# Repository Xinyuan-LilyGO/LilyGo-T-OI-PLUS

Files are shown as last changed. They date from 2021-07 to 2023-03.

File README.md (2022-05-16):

<h1 align = "center">🌟LILYGO T-OI-PLUS🌟</h1>

## **English | [中文](./README_CN.MD)**

<h3 align = "left">New version:</h3> 
**The new version has fixed the glitch that caused crystal burrs to start wifi and ble reset**

<h3 align = "left">Quick start:</h3>

**USE PlatformIO**

1. Install[VSCODE](https://code.visualstudio.com/)and[Python](https://www.python.org/)
2. Search for the PlatformIO plug-in in the VSCODE extension and install it.
3. After the installation is complete and the reload is completed, there will be a small house icon in the lower left corner. Click to display the Platformio IDE home page
4. Go to file - > Open folder - > Select the LilyGO-T-OI-PLUS folder and click the (√) symbol in the lower left corner to compile (→) for upload.

**USE Arduino IDE**

1. Install the current upstream Arduino IDE at the 1.8 level or later. The current version is at the [Arduino website](http://www.arduino.cc/en/main/software).
2. Start Arduino and open Preferences window. In additional board manager add url: https://raw.githubusercontent.com/espressif/arduino-esp32/gh-pages/package_esp32_index.json .separating them with commas.
3. Select Tools -> Board -> ESP32C3 Dev Module
4. If you do not have a driver installed, you need to install it (Window:ch341ser2.exe, MAC:ch34x_mac_driver_v1.6.zip [New driver reference](https://github.com/LilyGO/LILYGO-T-OI/issues/3#issuecomment-907645945 ))
5. Need to install the following dependencies
     - [Adafruit_NeoPixel](https://github.com/adafruit/Adafruit_NeoPixel)

**USE Micropython**

1. [Download and upload the firmware](https://micropython.org/download/esp32c3/)
2. Note that the firmware upload address is 0x0, not 0x1000.

<h3 align = "left">Product 📷:</h3>

|  Product  | Product  Link |
| :---: | :---: |
| T-OI-PLUS | [AliExpress](https://www.aliexpress.com/item/1005003348936965.html) |

## Pinout

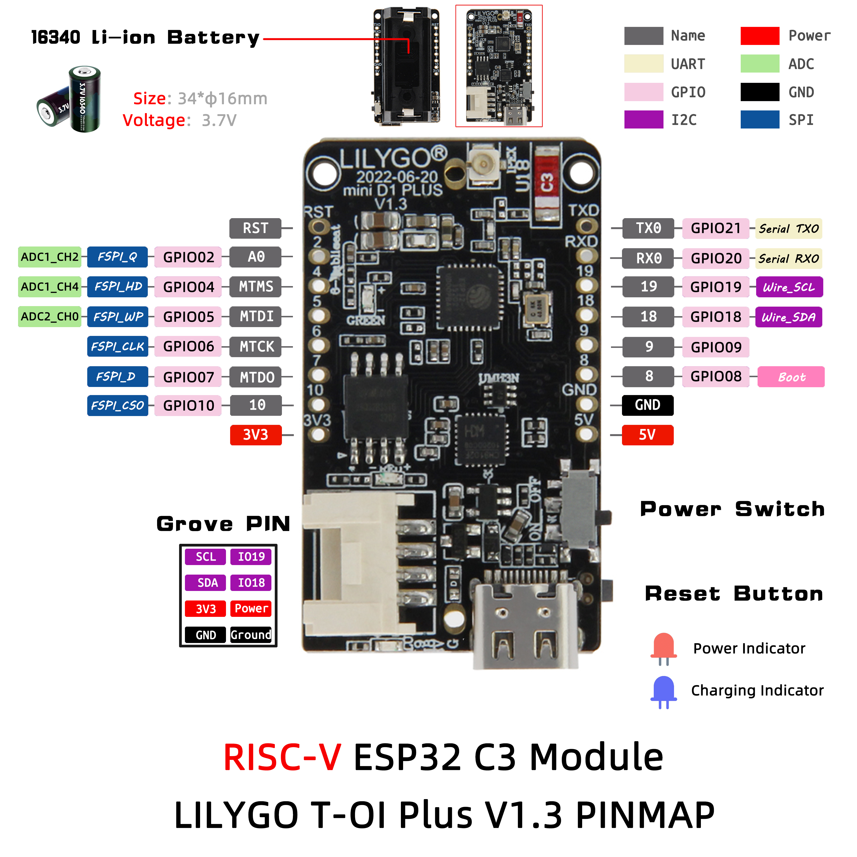
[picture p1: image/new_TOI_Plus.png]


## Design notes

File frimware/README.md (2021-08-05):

<h1 align = "center">🌟LILYGO T-OI-PLUS🌟</h1>

[Flash Download Tool](https://www.espressif.com/sites/default/files/tools/flash_download_tool_v3.8.8.zip)

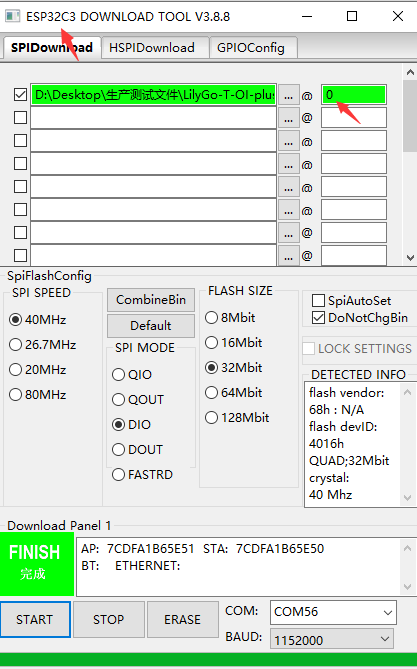
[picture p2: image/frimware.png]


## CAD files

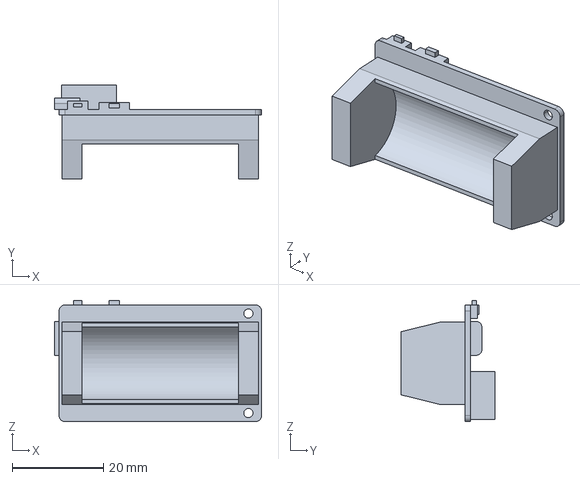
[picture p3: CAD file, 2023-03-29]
3D_File/T-Ol_Plus.stp
45.2 x 20.5 x 26.5 mm

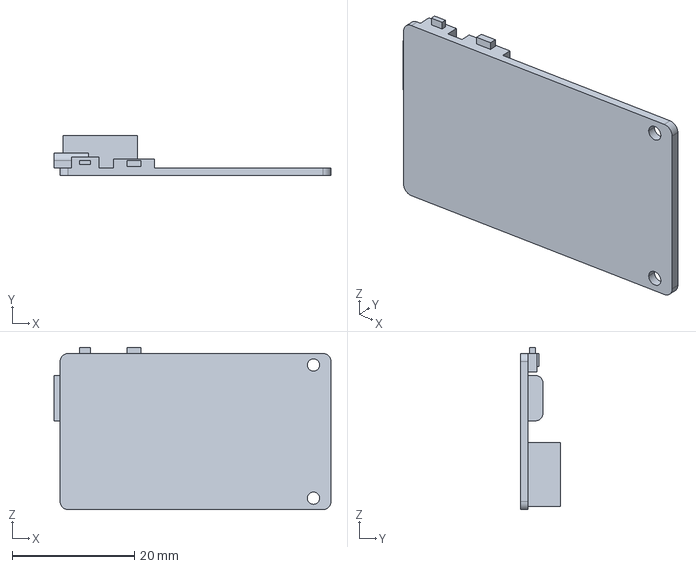
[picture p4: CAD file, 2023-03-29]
3D_File/T-OI_Plus(No_16340).stp
45.2 x 6.50 x 26.5 mm

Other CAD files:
T-OI_Plus.dwg

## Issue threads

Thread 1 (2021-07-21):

Schematic missing

TomasPech, 2021-07-21:
Hello, is schematic somewhere ?

gigamegawatts, 2021-08-15:
I have the same question.

LilyGO has been very good about providing schematics for their past products, which is a major reason why I bought them.  It's disappointing to see no schematic for this one.

gigamegawatts, 2021-08-16:
Ah, there it is.  Thank you for adding it!

LilyGO, 2021-09-02:
https://github.com/Xinyuan-LilyGO/LilyGo-T-OI-PLUS/tree/main/schematic

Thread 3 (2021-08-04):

with WiFi : cyclic reboot  "GLITCH_RTC_RST'

al1fch, 2021-08-04:
Hi ,

Same problem with  two T-OI-PLUS V1.1 boards : dont'work with WiFi exemples  from Arduino IDE + ESP32 2.0.0_rc1  core

|Board TTGO T-OI PLus (ESP32-C3)
|Version/date  : 1.1  20100716
|IDE name Arduino : 1.8.15 + ESP32 Core v 2.0.0-rc1
|Flash Frequency : 40 MHz
|PSRAM enabled : no
|Upload Speed : 115200
|Computer OS  :  Ubuntu

Description:
**Cyclic reboot (GLITCH_RTC_RST) as soon as WiFI start**s
Clean power, no glitch seen on scope for 3.3V rail

Sketch:
Any WiFI exemple for ESP32-C3 from Arduino IDE , even WiFIScan

Boot & Debug Messages:
`07:20:54.278 -> ESP-ROM:esp32c3-api1-20210207
07:20:54.278 -> Build:Feb 7 2021
07:20:54.278 -> rst:0x1 (POWEI (244) esp_image: segment 4: paddr=000b5ff8 vaddr=403863d0 size=069d8h ( 27096) load
07:20:54.278 -> I (250) esp_image: segment 5: paddr=000bc9d8 vaddr=50000000 size=00010h ( 16) load
07:20:54.278 -> I (254) boot: Loaded app from partition at offset 0x10000
07:20:54.278 -> I (254) boot: Disabling RNG early entropy source...
07:20:54.278 -> [ 276][D][esp32-hal-cpu.c:211] setCpuFrequencyMhz(): PLL: 480 / 6 = 80 Mhz, APB: 80000000 Hz
07:20:54.278 -> [ 300][D][WiFiGeneric.cpp:808] _eventCallback(): Arduino Event: 0 - WIFI_READY
07:20:54.420 -> [ 437][D][WiFiGeneric.cpp:808] _eventCallback(): Arduino Event: 2 - STA_START
07:20:54.520 -> Setup doneESP-ROM:esp32c3-api1-20210207
07:20:54.553 -> Build:Feb 7 2021
07:20:54.553 -> r**st:0x13 (GLITCH_RTC_RST),boot:0xd (SPI_FAST_FLASH_BOOT)**
07:20:54.553 -> SPIWP:0xee
07:20:54.553 -> mode:DIO, clock div:2
07:20:54.553 -> load:0x3fcd6100,len:0x142c
07:20:54.553 -> load:0x403ce000,len:0xbe8
07:20:54.553 -> load:0x403d0000,len:0x292c
07:20:54.553 -> SHA-256 comparison failed:
07:20:54.553 -> Calculated: a2104353fca28c61965343021ba4ec5ec5448cc15b2cdfcf01199ea0614dc0c5
07:20:54.553 -> Expected: 1b38c41cb11a47abdb84862e1e0376a06b2ed31c486f188e95161eb8c7db7a4e
07:20:54.586 -> Attempting to boot anyway...
07:20:54.586 -> entry 0x403ce000
07:20:54.586 -> I (49) boot: ESP-IDF v4.4-dev-2030-gd93887f9f-dirty 2nd stage bootloader
07:20:54.586 -> I (49) boot: compile time 01:17:48
07:20:54.586 -> I (49) boot: chip revision: 3
07:20:54.586 -> I (50) boot_comm: chip revision: 3, min. bootloader chip revision: 0
07:20:54.586 -> I (65) qio_mode: Enabling QIO for flash chip WinBond
07:20:54.586 -> I (65) boot.esp32c3: SPI Speed : 40MHz
07:20:54.619 -> I (65) boot.esp32c3: SPI Mode : QIO
07:20:54.619 -> I (68) boot.esp32c3: SPI Flash Size : 4MB
07:20:54.619 -> I (72) boot: Enabling RNG early entropy source...
07:20:54.619 -> I (77) boot: Partition Table:
07:20:54.619 -> I (79) boot: ## Label Usage Type ST Offset Length
07:20:54.619 -> I (86) boot: 0 nvs WiFi data 01 02 00009000 00005000
07:20:54.619 -> I (92) boot: 1 otadata OTA data 01 00 0000e000 00002000
07:20:54.653 -> I (99) boot: 2 app0 OTA app 00 10 00010000 00200000
07:20:54.653 -> I (105) boot: 3 spiffs Unknown data 01 82 00210000 001f0000
07:20:54.653 -> I (112) boot: End of partition table
07:20:54.653 -> I (115) boot_comm: chip revision: 3, min. application chip revision: 0
07:20:54.653 -> I (121) esp_image: segment 0: paddr=00010020 vaddr=3c090020 size=16950h ( 92496) map
07:20:54.743 -> I (144) esp_image: segment 1: paddr=00026978 vaddr=3fc8ce00 size=032c8h ( 13000) load
07:20:54.743 -> I (147) esp_image: segment 2: paddr=00029c48 vaddr=40380000 size=063d0h ( 25552) load
07:20:54.743 -> I (153) esp_image: segment 3: paddr=00030020 vaddr=42000020 size=85fd0h (548816) map
07:20:54.765 -> I (245) esp_image: segment 4: paddr=000b5ff8 vaddr=403863d0 size=069d8h ( 27096) load
07:20:54.765 -> I (250) esp_image: segment 5: paddr=000bc9d8 vaddr=50000000 size=00010h ( 16) load
07:20:54.789 -> I (255) boot: Loaded app from partition at offset 0x10000
07:20:54.789 -> I (255) boot: Disabling RNG early entropy source...
07:20:54.818 -> [ 277][D][esp32-hal-cpu.c:211] setCpuFrequencyMhz(): PLL: 480 / 6 = 80 Mhz, APB: 80000000 Hz
07:20:54.818 -> [ 301][D][WiFiGeneric.cpp:808] _eventCallback(): Arduino Event: 0 - WIFI_READY
07:20:54.951 -> [ 432][D][WiFiGeneric.cpp:808] _eventCallback(): Arduino Event: 2 - STA_START
07:20:55.051 -> Setup doneESP-ROM:esp32c3-api1-20210207
07:20:55.113 -> Build:Feb 7 2021
07:20:55.113 -> **rst:0x13 (GLITCH_RTC_RST),boot:0xd (SPI_FAST_FLASH_BOOT)**
... and so on...

Best regards

LilyGO, 2021-08-05:
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

 [Try this firmware](https://github.com/Xinyuan-LilyGO/LilyGo-T-OI-PLUS/tree/main/frimware)

al1fch, 2021-08-05:
Hi

Thank's for your precious answer and firmware to test!!

Whas this firmware produced with IDF or Arduino+ESP32 2.0.0-rc1 core ?

When your boards arrived they execute a original "WiFI Scan" code , so I WiFI is OK with this special code on T-OI board

After reading some infos from web , I came to following understanding :

1) Your recent T-OI boards came  with  'REVISION 3    ESP32-C3 chips' (good news !! less bugs!!!)

2) Present state of 2.0.0-rc1 core for ESP32 on Arduino IDE don't deal carefully with 'REVISION 3 ' chips

So I've put issue #5494 on ARDUINO/ESP32 CORE Github :
https://github.com/espressif/arduino-esp32/issues/5494

Many clients use Arduino IDE+core for your board so a solution on this side is important !!

Best regards,
Alain

----- Mail original -----
De: "LilyGO" ***@***.***>
À: "Xinyuan-LilyGO/LilyGo-T-OI-PLUS" ***@***.***>
Cc: "al1fch" ***@***.***>, "Author" ***@***.***>
Envoyé: Jeudi 5 Août 2021 04:46:09
Objet: Re: [Xinyuan-LilyGO/LilyGo-T-OI-PLUS] with WiFi : cyclic reboot  "GLITCH_RTC_RST' (#3)

Hi ,

Same problem with two T-OI-PLUS V1.1 boards : dont'work with WiFi exemples from Arduino IDE + ESP32 2.0.0_rc1 core

|Board TTGO T-OI PLus (ESP32-C3)
|Version/date : 1.1 20100716
|IDE name Arduino : 1.8.15 + ESP32 Core v 2.0.0-rc1
|Flash Frequency : 40 MHz
|PSRAM enabled : no
|Upload Speed : 115200
|Computer OS : Ubuntu

Description:
Cyclic reboot (GLITCH_RTC_RST) as soon as WiFI start s
Clean power, no glitch seen on scope for 3.3V rail

Sketch:
Any WiFI exemple for ESP32-C3 from Arduino IDE , even WiFIScan

Boot & Debug Messages:
`07:20:54.278 -> ESP-ROM:esp32c3-api1-20210207
07:20:54.278 -> Build:Feb 7 2021
07:20:54.278 -> rst:0x1 (POWEI (244) esp_image: segment 4: paddr=000b5ff8 vaddr=403863d0 size=069d8h ( 27096) load
07:20:54.278 -> I (250) esp_image: segment 5: paddr=000bc9d8 vaddr=50000000 size=00010h ( 16) load
07:20:54.278 -> I (254) boot: Loaded app from partition at offset 0x10000
07:20:54.278 -> I (254) boot: Disabling RNG early entropy source...
07:20:54.278 -> [ 276][D][esp32-hal-cpu.c:211] setCpuFrequencyMhz(): PLL: 480 / 6 = 80 Mhz, APB: 80000000 Hz
07:20:54.278 -> [ 300][D][WiFiGeneric.cpp:808] _eventCallback(): Arduino Event: 0 - WIFI_READY
07:20:54.420 -> [ 437][D][WiFiGeneric.cpp:808] _eventCallback(): Arduino Event: 2 - STA_START
07:20:54.520 -> Setup doneESP-ROM:esp32c3-api1-20210207
07:20:54.553 -> Build:Feb 7 2021
07:20:54.553 -> r st:0x13 (GLITCH_RTC_RST),boot:0xd (SPI_FAST_FLASH_BOOT)
07:20:54.553 -> SPIWP:0xee
07:20:54.553 -> mode:DIO, clock div:2
07:20:54.553 -> load:0x3fcd6100,len:0x142c
07:20:54.553 -> load:0x403ce000,len:0xbe8
07:20:54.553 -> load:0x403d0000,len:0x292c
07:20:54.553 -> SHA-256 comparison failed:
07:20:54.553 -> Calculated: a2104353fca28c61965343021ba4ec5ec5448cc15b2cdfcf01199ea0614dc0c5
07:20:54.553 -> Expected: 1b38c41cb11a47abdb84862e1e0376a06b2ed31c486f188e95161eb8c7db7a4e
07:20:54.586 -> Attempting to boot anyway...
07:20:54.586 -> entry 0x403ce000
07:20:54.586 -> I (49) boot: ESP-IDF v4.4-dev-2030-gd93887f9f-dirty 2nd stage bootloader
07:20:54.586 -> I (49) boot: compile time 01:17:48
07:20:54.586 -> I (49) boot: chip revision: 3
07:20:54.586 -> I (50) boot_comm: chip revision: 3, min. bootloader chip revision: 0
07:20:54.586 -> I (65) qio_mode: Enabling QIO for flash chip WinBond
07:20:54.586 -> I (65) boot.esp32c3: SPI Speed : 40MHz
07:20:54.619 -> I (65) boot.esp32c3: SPI Mode : QIO
07:20:54.619 -> I (68) boot.esp32c3: SPI Flash Size : 4MB
07:20:54.619 -> I (72) boot: Enabling RNG early entropy source...
07:20:54.619 -> I (77) boot: Partition Table:
07:20:54.619 -> I (79) boot: ## Label Usage Type ST Offset Length
07:20:54.619 -> I (86) boot: 0 nvs WiFi data 01 02 00009000 00005000
07:20:54.619 -> I (92) boot: 1 otadata OTA data 01 00 0000e000 00002000
07:20:54.653 -> I (99) boot: 2 app0 OTA app 00 10 00010000 00200000
07:20:54.653 -> I (105) boot: 3 spiffs Unknown data 01 82 00210000 001f0000
07:20:54.653 -> I (112) boot: End of partition table
07:20:54.653 -> I (115) boot_comm: chip revision: 3, min. application chip revision: 0
07:20:54.653 -> I (121) esp_image: segment 0: paddr=00010020 vaddr=3c090020 size=16950h ( 92496) map
07:20:54.743 -> I (144) esp_image: segment 1: paddr=00026978 vaddr=3fc8ce00 size=032c8h ( 13000) load
07:20:54.743 -> I (147) esp_image: segment 2: paddr=00029c48 vaddr=40380000 size=063d0h ( 25552) load
07:20:54.743 -> I (153) esp_image: segment 3: paddr=00030020 vaddr=42000020 size=85fd0h (548816) map
07:20:54.765 -> I (245) esp_image: segment 4: paddr=000b5ff8 vaddr=403863d0 size=069d8h ( 27096) load
07:20:54.765 -> I (250) esp_image: segment 5: paddr=000bc9d8 vaddr=50000000 size=00010h ( 16) load
07:20:54.789 -> I (255) boot: Loaded app from partition at offset 0x10000
07:20:54.789 -> I (255) boot: Disabling RNG early entropy source...
07:20:54.818 -> [ 277][D][esp32-hal-cpu.c:211] setCpuFrequencyMhz(): PLL: 480 / 6 = 80 Mhz, APB: 80000000 Hz
07:20:54.818 -> [ 301][D][WiFiGeneric.cpp:808] _eventCallback(): Arduino Event: 0 - WIFI_READY
07:20:54.951 -> [ 432][D][WiFiGeneric.cpp:808] _eventCallback(): Arduino Event: 2 - STA_START
07:20:55.051 -> Setup doneESP-ROM:esp32c3-api1-20210207
07:20:55.113 -> Build:Feb 7 2021
07:20:55.113 -> rst:0x13 (GLITCH_RTC_RST),boot:0xd (SPI_FAST_FLASH_BOOT)
... and so on...

Best regards

Try this firmware

—
You are receiving this because you authored the thread.
Reply to this email directly, view it on GitHub , or unsubscribe .
Triage notifications on the go with GitHub Mobile for iOS or Android .

tomash, 2021-08-10:
Confirming, same board, same issue.

al1fch, 2021-08-28:
Thank @tomash for the 2 working tricks !!

Somethig is coming on ESP32 core side :
[https://github.com/espressif/arduino-esp32/issues/5601](url)

Closed 2021-09-02.

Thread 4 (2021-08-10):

wifi: no connectivity as STA and softAP

yshestakov, 2021-08-10:
Hi,

I'm trying to compile and run examples/wifi/getting_started/ code having `CONFIG_ESP32_PHY_MAX_WIFI_TX_POWER=14`.
It seems the module is not able to connect to wifi nor become visible as softAP.
Tested on `v4.4-dev` branch and current "master" (83956ebbae5b3)

gigamegawatts, 2021-08-16:
I have the same problem.

I tested with ESP-IDF v4.3 (Jun 15 release), and with Arduino.  I've set the Tx power to 12 and disabled brownout to prevent the "reset glitch" problem.

There aren't any runtime errors, but the "station" example fails to connect to the SSID (I've tried 3 different routers), and the "softAP" example's access point isn't visible.

The "scan" example works, so the WiFi hardware is functioning.

I've tested with 2 different T-OI-Plus modules, both silicon revision 3.

Is everybody having problems with these 2 examples?  If anyone has got them to work, or has been able to connect to an access point using a different approach, I'd appreciate if you could reply and say so.  If you have any suggestions on code changes, that would be very helpful.

Thanks,

Dan.

mgsb, 2021-08-16:
I am seeing the same issue. I also tried latest espressif Arduino support (2.0.rc1) and the client example fails to connect as well. scan works for me, too.

gigamegawatts, 2021-08-17:
I was able to get the "station" and "softAP" ESP-IDF examples to work by using the "LilyGo-T-OI-plus_2021-7-17.bin" firmware in this GitHub.

I assume that this replacement bootloader makes some tweaks to the WiFi behaviour.  Unfortunately, without the source code it's impossible to know for sure.

I haven't done anything ambitious yet with the WiFi code, or retested with Arduino, so I don't know how much is fixed by the replacement bootloader. It's a step in the right direction, at least.

Note that you have to be careful not to overwrite the bootloader when you flash your code.  I run esptool.py from the command line without the "0x0 build\bootloader\bootloader.bin" part.

yshestakov, 2021-08-17:
The `LilyGo-T-OI-plus_2021-7-17.bin` file has been built using ESP-IDF version `v4.4-dev-960-gcf457d412`:

```commit 7bb5c8cc82c647316802f051cff30a61ddcc2b5e (tag: gcf457d412)
Author: Angus Gratton <angus@espressif.com>
Date:   Fri Apr 23 10:15:50 2021 +1000

    esp32c3 espefuse: Fix efuse programming timing on ESP32-C3 ECO3

    Without this timing change, efuse programming occasionally appears to fail
    (although the efuse is programmed correctly).
```

I tried to check out gcf457d412  tag, have rebuilt "examples/wifi/stations". There is no issue with TX_POWER / TX_WIFI_POWER (set to 20 in sdkconfig). However, the station doesn't work: not able to connect to my AP.

Well, the "scan" example works fine in the "master" branch as well.
By the way, I saw the "station" connected to my AP once, then it rebooted immediately and failed to connected after reboot.
I can't reproduce it again. Probably, it was the case when "scan" was replaced by "station" application, it worked for a moment and stopped to work after that.
So, there is something wrong with wifi authentication or wifi connectivity settings.

p.s. the latest one (master branch) I tested has `v4.4-dev-2594-ga20df` tag assigned.

gigamegawatts, 2021-08-17:
@yshestakov I get a different result from you: AP connect works (and has been stable so far) with TX_POWER set to 12.  If I change the TX_POWER to 20, it can no longer connect to the AP -- it doesn't reset or hang, it just gives the usual "connect to the AP fail" error message.  I'm using the ESP-IDF v4.3 release, not 4.4-dev.

I'm quite sure that the fix in my case was in that LilyGo-T-OI-plus_2021-7-17.bin bootloader.  I tried going back to the default bootloader from my ESP-IDF build, and I can no longer connect to the AP.

However, that new bootloader doesn't fix everything.  I tried connecting to an eero router, and that failed.  In fact, the eero AP doesn't even show up in the scan results.  So, it works with one AP (an old Wavlink), but not with another.

yshestakov, 2021-08-18:
@gigamegawatts thank you for the information regarding `v4.3` release you're using.
In fact, I have 4 boards bought (2 with battery holder and 2 w/o it)
One of boards is not visible in the "softAP" application (`myssid`). However, the second one is visible in the "Wifi Analyzer" (Android app).
So that I have unpacked 3rd board, flashed "station" app and got it connected to the `myssid` just of a couple of seconds:

```I (623) wifi:enable tsf
I (623) wifi station: wifi_init_sta finished.
I (623) wifi:new:<1,1>, old:<1,0>, ap:<255,255>, sta:<1,1>, prof:1
I (633) wifi:state: init -> auth (b0)
I (643) wifi:state: auth -> assoc (0)
I (663) wifi:state: assoc -> run (10)
I (10663) wifi:state: �ESP-ROM:esp32c3-api1-20210207
Build:Feb  7 2021
rst:0x13 (GLITCH_RTC_RST),boot:0xd (SPI_FAST_FLASH_BOOT)
SPIWP:0xee
mode:DIO, clock div:2
```

WIFI_TX_POWER is set to 12 in all cases.
ESP-IDF:          v4.4-dev-2594-ga20df743f1-dirty

yshestakov, 2021-08-18:
Having added call to `esp_wifi_set_country()` with MANUAL policy and max_power=12, I'm able to see a successful Wifi connection established by the station. But it lasts only for a couple seconds again:

```I (483) wifi:set country: cc=US schan=1 nchan=14 policy=1

I (493) phy_init: phy_version 500,985899c,Apr 19 2021,16:05:08
I (613) wifi:set rx active PTI: 0, rx ack PTI: 0, and default PTI: 0
I (613) wifi:mode : sta (7c:df:a1:b6:58:9c)
I (613) wifi:enable tsf
I (623) wifi:new:<1,1>, old:<1,0>, ap:<255,255>, sta:<1,1>, prof:1
I (623) wifi:state: init -> auth (b0)
I (623) wifi:state: auth -> assoc (0)
I (1633) wifi:state: assoc -> init (400)
I (1633) wifi:new:<1,0>, old:<1,1>, ap:<255,255>, sta:<1,1>, prof:1
I (3323) wifi:new:<1,1>, old:<1,0>, ap:<255,255>, sta:<1,1>, prof:1
I (3323) wifi:state: init -> auth (b0)
I (3333) wifi:state: auth -> assoc (0)
I (3333) wifi:state: assoc -> run (10)
I (13333) wifi:state: run -> init (cc00)
I (13333) wifi:new:<1,0>, old:<1,1>, ap:<255,255>, sta:<1,1>, prof:1
I (15033) wifi:new:<1,1>, old:<1,0>, ap:<255,255>, sta:<1,1>, prof:1
I (15033) wifi:state: init -> auth (b0)
I (15033) wifi:state: auth -> assoc (0)
�ESP-ROM:esp32c3-api1-20210207
Build:Feb  7 2021
rst:0x13 (GLITCH_RTC_RST),boot:0xd (SPI_FAST_FLASH_BOOT)
```

yshestakov, 2021-08-18:
Update.
I have checked out esp-idf and its submodules including `components/esp_wifi/lib` to the commit dated on April 7:
```commit 4702feeeebcd4ccb3090f4747f96aea6d719f432 (HEAD, tag: 20210407)
Author: Zhang Jun Hao <zhangjunhao@espressif.com>
Date:   Wed Apr 7 15:04:51 2021 +0800

    esp_wifi: move unused wifi log to noload section to save binary size
```

As a result, I got wifi station app connected to my AP (partially): I didn't get IP address assigned.

```I (479) wifi:set country: cc=US schan=1 nchan=14 policy=1
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
gigamegawatts, 2021-08-24:
@tomash I was wondering too if other C3 boards like Espressif's DevKit have WiFi problems.  I haven't read about any.

The DevKits use shielded modules, and apparently don't use external flash (there are variants of the ESP-C3 that have on-chip flash).  I wonder if one of those differences causes the WiFi problems.  Just a wild guess, but maybe the external flash causes some critical code to run too slowly, resulting in a connection timeout?

The fact that LilyGo has stopped selling the IO-PLUS makes me suspect it is a problem specific to the board.

Let us know how it goes with the other board.

tomash, 2021-08-25:
@gigamegawatts after I test with devkits, I'll sacrifice one of my Lilygo boards and desolder the flash chip to see if it helps. It's the BergMicro 25Q32 near the grove connector and 3V3 pin, right?

gigamegawatts, 2021-08-27:
@tomash Thanks for letting us know.  That's good news, at least for Espressif.   It means that the problem isn't with the C3 or the  Espressif WiFi stack.

Do your DevKits have the "revision 3" C3?  (The GetChipID Arduino sketch displays the revision.)   Apparently this revision has some differences that affect WiFi.  I wondered if people aren't having WiFi problems with the Espressif DevKits because they use an earlier revision.

Do you mind saying where you bought your boards from?  I'd like to have a reliable board to test with.

As for the antenna on the IO-PLUS, that's worth a try, since I don't have a better idea.  Although the ceramic antenna works with one of my routers, I might try changing it myself out of curiosity.

gigamegawatts, 2021-08-30:
@tomash I just tried changing to a uFL antenna (and moved the R0 resistor over to its connection pad).  For me, it made no difference - same AP connection results.  RSSI was actually a little worse with this antenna, but it's a cheapo model that cost a couple of dollars on Aliexpress.

If you have a better antenna and your signal strength is poor with the ceramic antenna, it might be worth trying anyway.  At least, I can confirm that the uFL antenna works.

wibbler, 2021-09-12:
I don't know if this is relevant, but I'm climbing up the wall trying to get BLE working on these boards, I have two  20120716 boards, both act the same , advertising now and again, scanning never. I'm using esp-idf-4.3.1. I've tried all sorts of things, I really am beginning to believe the RF side of these boards are borked. I'll try 4.4 and master or whatever, but lost two days trying to get esp-idf example code working (as well as my own known good code), very disappointed with lilygo

gigamegawatts, 2021-09-12:
@wibbler I hadn't tried BLE before today, but I have problems too with my 20210716 board.

I only tried GATT server examples: advertising works, but I can't connect.  No connect or disconnect event is raised by the ESP-IDF code.  It would seem that whatever's going wrong is happening in hardware, since I don't see any related BLE issues in the ESP-IDF Github.

I tried the Nimble, BlueDroid (both ESP-IDF 4.3) and even the Arduino BLE stacks, and get the same result in each case.

So, yeah, assuming that there aren't some other users happily using Wi-Fi and BLE with the OI PLUS, something's borked on the RF side.  LilyGo stopped selling this board a while ago, and that might be the closest thing we get to a confirmation from them.

I notice that LilyGo has recently started selling their own C3 module (i.e. just the SOC without a board).  There's not much info on their site, but the obvious differences from the OI PLUS are a PCB antenna and a metal shielding enclosure.  Imma pass on that one.

Jason2866, 2021-09-13:
The board is borked. Every other C3 boards do work, including BLE.

LilyGO, 2021-09-29:
Sorry for the inconvenience, the new version has been updated to fix it.

krystiansliwa, 2021-09-29:
@LilyGO New version of board?

LilyGO, 2021-09-29:
[New version](https://it.aliexpress.com/item/1005003348936965.html)

krystiansliwa, 2021-09-29:
Do you plan to replace broken ones?

LilyGO, 2021-09-29:
Yes, you can contact the customer for replacement

gigamegawatts, 2021-10-06:
I received the exact same reply.  I don't know what it means either.

I also wonder what they've changed in the new version of the board.  The antenna is obviously different, but they've also reoriented the chip and surrounding components.  The notice on this Github says "The new version has fixed the glitch that caused crystal burrs to start wifi and ble reset", which doesn't mean much to me.

LilyGO, 2021-10-06:
Customer service needs you to provide a screenshot of the reset serial port after wifi is turned on

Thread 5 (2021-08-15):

How to measure battery level in code?

gigamegawatts, 2021-08-15:
Is the battery connected to an ADC on the ESP32-C3, so we can measure its level?

gigamegawatts, 2021-08-17:
Now that they've added the schematic, I can answer my own question.  The battery is connected to A0 (ADC1_CH2) through a 1:1 voltage divider.

I've confirmed that the voltage value on A0 is correct using a multimeter.  (I haven't read up on the C3's ADC yet, but the ADC code returns a value that is higher than expected by about 12%.  At least the value is consistent.)

mr-pl3r, 2022-01-17:
Hi @gigamegawatts ,

How did you end up measuring the A0 reading?

I have tried the next formula to get the data, but it's still not working for me...first I identify the g_vref with the next code and then use it on the formula to get the aprox voltage.
`
float g_vref = 24637;  //Two Point --> coeff_a:24637mV coeff_b:0mV   <<<<< This is the result I always get

void adc_vref_init(){
    esp_adc_cal_characteristics_t adc_chars;
    esp_adc_cal_value_t val_type = esp_adc_cal_characterize((adc_unit_t)ADC_UNIT_1, (adc_atten_t)ADC1_CHANNEL_2, (adc_bits_width_t)ADC_WIDTH_BIT_12, 1100, &adc_chars);
    //Check type of calibration value used to characterize ADC
    if (val_type == ESP_ADC_CAL_VAL_EFUSE_VREF) {
        Serial.printf("eFuse Vref:%u mV\n", adc_chars.vref);
        g_vref = adc_chars.vref;
    } else if (val_type == ESP_ADC_CAL_VAL_EFUSE_TP) {
        Serial.printf("Two Point --> coeff_a:%umV coeff_b:%umV\n", adc_chars.coeff_a, adc_chars.coeff_b);
    } else {
        Serial.println("Default Vref: 1100mV");
    }
}
//This formula is what I use to get the voltage - but it's not consistent and returning readings all over the place.
float v = analogRead(A0);
float battery_voltage = ((float)v / 4095.0) * 2.0 * 3.3 * (g_vref / 1000.0);
`

Thank you in advance for your help,

gigamegawatts, 2022-01-17:
Hi @mr-pl3r ,

I based my code on the ESP-IDF's example (in the ESP-IDF folder, it's in examples\peripherals\adc\esp32c3\adc).

It uses code that is different from the example for the ESP32 and ESP32-S2.

My code is based on the esp32c3 example's single_read() function:
```

static int read_battery()
{
    int32_t adc_total = 0;

    adc1_config_width(ADC_WIDTH_BIT_DEFAULT);
    adc1_config_channel_atten(ADC1_CHANNEL_2, ADC_ATTEN_DB_11);

    int n = 20;
    while (n--) {
        adc_total += adc1_get_raw(ADC1_CHANNEL_2);
    }

    int average_adc = adc_total / 20;
    ESP_LOGI(TAG, "raw battery adc %d", average_adc);

    return average_adc;
}
```

The formula I used to convert the adc reading to volts is 6*average_adc/4095.  I think I just made up that formula, but it was close enough for my purposes.

Dan.

mr-pl3r, 2022-01-17:
@gigamegawatts  Thank you for the info, I will give it a shot with your code and report back if I see something wrong.
Take it easy!

mr-pl3r, 2022-01-18:
@gigamegawatts
After some testing I was able to come up with the error % , therefore the formula I have is :

  float battery_voltage = ((2*3.3*v)/4095)-.23;

BTW - I needed to change this line
From:
adc1_config_width(ADC_WIDTH_BIT_DEFAULT);
To:
adc1_config_width(ADC_WIDTH_12Bit); //since SC3 is always 12 bit and it was throwing an error on Arduino IDE according to the espressif document shown below.

https://github.com/espressif/esp-idf/blob/187e6ff66f653ac21fb6ab67e3cc8cc3a571b032/components/driver/adc.c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

gigamegawatts, 2022-01-20:
@mr-pl3r  I'm glad you got it to work.

I didn't realize you were using Arduino.  I thought the Arduino code was taken from ESP-IDF, but I guess some things are different.   I'm using ESP-IDF with Espressif's build system, and ADC_WIDTH_BIT_DEFAULT is the same as ADC_WIDTH_BIT_12 (3).  You're right: only 12-bit is supported by the ESP32-C3.

I originally used ESP-IDF 4.3.0.  Out of curiosity, I just tried the latest release, ESP-IDF 4.4 RC1.  In this release they've refactored the ADC code, so the ESP32-C3 example I originally used doesn't exist.  I used the closest thing, an example named single_read.

It still works OK, and adc1_get_raw() returns similar values to 4.3.0.  The value jumps around a lot (by about 3%), so it's still necessary to read it a bunch of times and average the result.  The single_read example calls esp_adc_cal_raw_to_voltage(), but the result isn't even close.

gigamegawatts, 2022-02-10:
@roomme13  I guess you're referring to my comment about esp_adc_cal_raw_to_voltage() not working properly?

Sorry, I was exaggerating when I wrote "isn't even close".  I just tested again, and that function returned an average of 2124.  My multimeter measured 2063, so that's not bad, about 3% too high.   (It returns half the actual battery voltage, since the T-IO-PLUS uses a 1:1 voltage divider to connect the battery to A0.  The actual battery voltage measured by my multimeter was 4.13V)

I don't know what accounts for the 3% error.  It might be a software problem in their SDK, but not necessarily.  It might be  related to the "eFuse" parameters that are burned into the chip.  My T-IO-PLUS is an older one, with the board dated 20210716.  LilyGo released a newer version in September -- I don't have it, but perhaps I would get a better result with that one.

3% is probably close enough when measuring the battery.  For other purposes where you need a more accurate measurement, the easiest solution is to use a separate ADC breakout board with a chip like the MCP3002.

Closed 2021-08-17.

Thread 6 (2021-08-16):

Turn off power LED

dogsop, 2021-08-16:
Can the power LED be disabled in software to cut down the power drain when running on battery?

mgsb, 2021-08-16:
The schematic (https://raw.githubusercontent.com/Xinyuan-LilyGO/LilyGo-T-OI-PLUS/main/schematic/T-OI_PLUS_Schematic.pdf) shows the red LED hardwired to Vdd33.

dogsop, 2021-08-17:
> The schematic (https://raw.githubusercontent.com/Xinyuan-LilyGO/LilyGo-T-OI-PLUS/main/schematic/T-OI_PLUS_Schematic.pdf) shows the red LED hardwired to Vdd33.

The schematic is wrong, at least for the version I got. The red LED is wired to a GPIO pin, the green LED is wired to power. I was having trouble following the schematic and was hoping that it was also possible to turn off the green LED.

gigamegawatts, 2021-08-17:
I noticed that the photos of the board on Lilygo's AliExpress site are of an older version of the board.  Their photos show a board labelled 20210625, with the green LED in the middle.

My board is labelled 20210716, version 1.1.  It has the green LED on the outside and the red LED in the middle.  On this board, the green LED is controlled through GPIO 3, while the red LED is always on when the board is powered.  So, the schematic seems to be for the newer version of the board.

Incidentally, LilyGo's AliExpress page for this board now says "Sorry, this item is no longer available!"  I don't know if that means out-of-stock, or discontinued.

mgsb, 2021-08-17:
Yes, I have v1.1 board, too, which appears to match the schematic. The LEDs, from left to right are:
* Green - controlled by GPIO03
* Red - power
* Blue - USB (charging)

al1fch, 2021-08-28:
OK with @gigamegawatts and @msg for V.1.1  board (2021 07 16)

Power red led is easy to remove...

LilyGO, 2021-09-30:
If you don't want to stick red power lights, you can note with customer service.

Closed 2021-10-19.

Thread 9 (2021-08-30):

Board "ESP32C3 Dev Module" not found in the list of boards for ESP32

edmund-troche, 2021-08-30:
I've used the boards index in the README.md, but there is no board with the name "ESP32C3 Dev Module". Did the board name change from the T-IO-Plus? Should I use a different board list?

Thanks

al1fch, 2021-08-30:
@edmund-troche

ESP32-C3 is (partially) supported by 2.0.0-RC2 version if the core fir Arduino IDE, so ESP32C3 Dev Module is seen in  board's list for this version

edmund-troche, 2021-08-30:
@al1fch Thanks for the info, I'll check it out

Closed 2021-08-30.

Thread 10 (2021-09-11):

Very bad wifi signal

Jason2866, 2021-09-11:
Compiled a Arduino ESP32 framework with the glitch fix (#3).
https://github.com/Jason2866/esp32-arduino-lib-builder/releases/download/427/framework-arduinoespressif32-master-583026f04.tar.gz So https://github.com/espressif/esp-idf/issues/7082 is solved. No more boot loops. But signal is -76dBM at 1 meter of Wifi AP, far too low.
Source code: https://github.com/arendst/Tasmota
Compiled binary https://jason2866.github.io/Tasmota-specials/
Other C3 (revision 3 too) boards do work without any issue!
See screenshot from running Tasmota on a AI-Thinker ESP-C3-01M module
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

LilyGO, 2021-09-29:
Sorry for the inconvenience, the new version has been updated to fix it.

Closed 2021-10-06.

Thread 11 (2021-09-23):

JTAG debugging over USB cable

jeancf, 2021-09-23:
[Espressif documentation](https://docs.espressif.com/projects/esp-idf/en/release-v4.3/esp32c3/api-guides/jtag-debugging/index.html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) mentions that the ESP32-C3 has built-in JTAG functionality and that "JTAG debugging is through an USB cable connected to the D+/D- USB pins of ESP32-C3. No need for an external JTAG adapter and extra wiring / cable to connect JTAG to ESP32-C3."

When I launch `openocd -f board/esp32c3-builtin.cfg` with the USB cable connected however I get:

```
Open On-Chip Debugger  v0.10.0-esp32-20210401 (2021-04-01-15:45)
Licensed under GNU GPL v2
For bug reports, read
	http://openocd.org/doc/doxygen/bugs.html
Info : only one transport option; autoselect 'jtag'
Warn : Transport "jtag" was already selected
force hard breakpoints
Info : Listening on port 6666 for tcl connections
Info : Listening on port 4444 for telnet connections
Error: esp_usb_jtag: could not find or open device!
```

Am I using the wrong openocd config? How does this work?

Thanks.

gigamegawatts, 2021-09-24:
The USB JTAG support works well on the OI-PLUS for me, but I'm using a commercial product that makes things easy, VisualGDB.

I just did a quick test with ESP-IDF 4.3.  Debugging works for me, using the same command and version of openocd as you, but flashing doesn't.  Apparently the flashing problem is fixed in a later release of openocd -- https://github.com/espressif/openocd-esp32/releases/tag/v0.10.0-esp32-20210721.

Are you using the USB port on the OI-PLUS?  I don't think that can be made to work.  Instead, you need to connect a USB breakout board to 5V, GND, GPIO18 and GPIO19, as described here: https://visualgdb.com/tutorials/esp32/esp32-c3/.

Also,  you need to use a WinUSB driver from Espressif, as described here: https://docs.espressif.com/projects/esp-idf/en/latest/esp32c3/api-guides/jtag-debugging/configure-builtin-jtag.html.  I had to manually switch to their driver using this tool: https://visualgdb.com/UsbDriverTool/.

I hope that helps.

Dan.

jeancf, 2021-09-25:
Thanks for your response Dan.

> Are you using the USB port on the OI-PLUS?

I was. Thanks to you I re-read the instructions and now realise that I am suposed to connect with a USB cable **through a USB-to_TTL adapter** to GPIO18, GPIO19, 5V and GND pins of the board.

I also updated openocd-esp32 to the version that you mentioned (2021-07-21). I am using linux therefore I do not need a driver. However the command `openocd -f board/esp32c3-builtin.cfg` still returns the same `Error: esp_usb_jtag: could not find or open device!`. I tried swapping the wires connected to GPIO18 and GPIO19 witth the same result.

Do you have to specify somehow to which COM device the USB adapter is connected? Otherwise, how would openocd know where to find it...

Thanks.

gigamegawatts, 2021-09-25:
Hi,

I just tried running on Linux, specifically Ubuntu 20.04.

It works for me.  I suspect the difference is that I (unintentionally) installed the 4.4-dev version of ESP-IDF.  Based on my Googling, it seems that USB JTAG support is flaky in ESP-IDF 4.3.x.

Other than that, the only problem I had to deal with was the udev settings.  I think you've already done that, since you didn't get any LIBUSB errors, but you definitely need the udev rules in order for openocd to work.  The udev rules I used are from https://github.com/espressif/openocd-esp32/blob/master/contrib/60-openocd.rules.

I also had problems once I connected with gdb: the gdb session timed out, and the openocd session would have a lot of "usb received only x out of y bytes".  I fixed that by lowering the adapter speed setting.

The openocd command line I ended up using is:
`openocd -f interface/esp_usb_jtag.cfg -c "adapter_khz 3000" -f target/esp32c3.cfg`

I actually don't know openocd at all - I just copied this from what VisualGDB uses. Maybe the board parm would work, and maybe the interface parm isn't needed, but the above works for me.

Flashing still doesn't work for me.  I found that you can disconnect the 5V cable on the USB breakout board (the one used for JTAG), then connect a second cable to the OI-PLUS's USB C port, then flash the code through USB.

I hope that helps.

Dan.

jeancf, 2021-09-27:
The problem is that I kept trying to connect to the GPIO18 and GPIO19 port through a [USB-to TTL adapter](https://www.amazon.com/usb-ttl-adapter/s?k=usb+to+ttl+adapter). Actually the link that you provided (https://visualgdb.com/tutorials/esp32/esp32-c3/) shows that the USB wires have to be directly connected to the pins. Also, the data sheet specifies that  GPIO18 and GPIO19 pins provide USB D+/D- signals, not UART TX/RX.

That option is a lot less appealing than my original expectation of debugging through the USB-C connector of the board. I am going to try to use an external JTAG probe instead (and burn the corresponding fuse).

Anyway, thanks a lot for your help. I hope that flashing gets resolved soon to simplify your process.

Thanks.

gigamegawatts, 2021-09-27:
For what it's worth, flashing through the USB JTAG connection does work for me now.  I actually don't know what changed from when it failed on Saturday, so this feature might be flaky, or maybe just user error.

Here's what worked for flashing the hello-world sample - it's the same as in the Espressif docs.  As mentioned, I'm using the 4.4dev version of ESP-IDF, so the openocd version is more recent than the one I linked to earlier.

```
openocd -f board/esp32c3-builtin.cfg -c "program_esp build/hello-world.bin 0x10000 verify exit"
```
Output:

```
Open On-Chip Debugger  v0.10.0-esp32-20210902 (2021-09-02-09:38)
Licensed under GNU GPL v2
For bug reports, read
        http://openocd.org/doc/doxygen/bugs.html
Info : only one transport option; autoselect 'jtag'
Warn : Transport "jtag" was already selected
Info : esp_usb_jtag: Device found. Base speed 40000KHz, div range 1 to 255
Info : clock speed 40000 kHz
Info : JTAG tap: esp32c3.cpu tap/device found: 0x00005c25 (mfg: 0x612 (Espressif Systems), part: 0x0005, ver: 0x0)
Info : datacount=2 progbufsize=16
Info : Examined RISC-V core; found 1 harts
Info :  hart 0: XLEN=32, misa=0x40101104
Info : Listening on port 3333 for gdb connections
Info : JTAG tap: esp32c3.cpu tap/device found: 0x00005c25 (mfg: 0x612 (Espressif Systems), part: 0x0005, ver: 0x0)
Info : Flash mapping 0: 0x10020 -> 0x3c020020, 24 KB
Info : Flash mapping 1: 0x20020 -> 0x42000020, 87 KB
Info : Auto-detected flash bank 'esp32c3.flash' size 4096 KB
Info : Using flash bank 'esp32c3.flash' size 4096 KB
** Programming Started **
Info : PROF: Data transferred in 2726.99 ms @ 58.6727 KB/s
** Programming Finished **
** Verify Started **
** Verified OK **
shutdown command invoked
```

To clarify the type of USB connection I'm using, it's a simple breakout board like this one: https://www.adafruit.com/product/1764.  I think a breakout cable like this would also work, though I don't own one: https://www.adafruit.com/product/4448

jeancf, 2021-09-29:
I did not want to wait for the delivery of a breakout adapter so I built a frankencable with an old usb cable that cut and soldered to 4 Dupont wires.

On the software side, I deleted the complete esp-idf installation and restarted from scratch with the master branch. After a few I managed to get it installed correctly. Like you, I am now able to do build and upload the binary over the built-in JTAG interface at last. I am not able to debug it yet though. Launching `idf.py gdb` fails with
```
Executing action: gdb
riscv32-esp-elf-gdb: error while loading shared libraries: libpython2.7.so.1.0: cannot open shared object file: No such file or directory
```
This sounds like riscv32-esp-elf-gdb is built with python 2.7 but I only have python 3.9 installed. I don´t feel like installing python 2.7 just for this. Do you have python 2.7 installed?

gigamegawatts, 2021-09-29:
Yes, I do: Python 2.7.18.  That library was installed by the libpython2.7 package.

I had no idea Python 2.7 was prereq for riscv32-esp-elf-gdb or any other part of ESP-IDF -- there's no mention of it in the ESP-IDF prereqs page.  I must have installed Python 2.7 a long time ago for some other project.

Seems like yet another bug in the ESP-IDF support for this chip, though I don't see any issues about it on the ESP-IDF Github.   If you don't want to install Python 2.7 (or maybe installing just libpython2.7 would work?), maybe you should open an issue on the ESP-IDF Github - they might provide a fix or workaround.

jeancf, 2021-10-01:
I installed python 2.7 for now and this problem is resolved. I reported the issue to Espressif (https://github.com/espressif/openocd-esp32/issues/181).

Now when I start gdb I get:
```
Ignoring packet error, continuing...
warning: unrecognized item "timeout" in "qSupported" response
/home/jeancf/Documents/esp32c3/hello_world/build/gdbinit:2: Error in sourced command file:
Remote replied unexpectedly to 'vMustReplyEmpty': PacketSize=4000;qXfer:memory-map:read+;qXfer:features:read+;qXfer:threads:read+;QStartNoAckMode+;vContSupported+
```

At the same time, on the side of openocd I see:
```
Info : accepting 'gdb' connection on tcp/3333
Warn : No symbols for FreeRTOS!
Info : Flash mapping 0: 0x10020 -> 0x3c020020, 26 KB
Info : Flash mapping 1: 0x20020 -> 0x42000020, 88 KB
Info : Auto-detected flash bank 'esp32c3.flash' size 2048 KB
Info : Using flash bank 'esp32c3.flash' size 2048 KB
Info : Flash mapping 0: 0x10020 -> 0x3c020020, 26 KB
Info : Flash mapping 1: 0x20020 -> 0x42000020, 88 KB
Info : Using flash bank 'esp32c3.irom' size 92 KB
Info : Flash mapping 0: 0x10020 -> 0x3c020020, 26 KB
Info : Flash mapping 1: 0x20020 -> 0x42000020, 88 KB
Info : Using flash bank 'esp32c3.drom' size 28 KB
Warn : negative reply, retrying
Warn : negative reply, retrying
Warn : negative reply, retrying
Error: GDB missing ack(2) - assumed good
Error: GDB missing ack(2) - assumed good
Error: GDB missing ack(2) - assumed good
Info : dropped 'gdb' connection
```

gdbinit file:
```
file /home/jeancf/Documents/esp32c3/hello_world/build/hello-world.elf
target remote :3333
mon reset halt
flushregs
thb app_main
c
```

Neverending nightmare...

gigamegawatts, 2021-10-01:
That "Error in sourced command file" might be the cause.

I'm using a slightly different gdbinit without the file command -- I copied it from the [docs](https://docs.espressif.com/projects/esp-idf/en/latest/esp32c3/api-guides/jtag-debugging/using-debugger.html):

```
target remote :3333
set remote hardware-watchpoint-limit 2
mon reset halt
flushregs
thb app_main
c
```
I specify the .elf file in the gdb command line instead:

riscv32-esp-elf-gdb -x gdbinit build/hello-world.elf

jeancf, 2021-10-06:
I filed an [issue](https://github.com/espressif/openocd-esp32/issues/182) with Espressif and I am waiting for a reaction.

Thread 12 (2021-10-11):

New MacOS 11.6 (Big Sur) driver for the CH340K available (28.August 2021)

TMillesich, 2021-10-11:
Thank https://github.com/eschwim for his great help!

https://github.com/LilyGO/LILYGO-T-OI/issues/3#issuecomment-907645945

Closed 2022-10-19.

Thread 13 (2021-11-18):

Micropython for this board

wolfen351, 2021-11-18:
Hi there
I'm new at this, but I understand I need to flash micropython onto the board before I can write python code for it. Where can I find that image?

Thanks!

ryanaross, 2021-11-19:
I was able to flash micropython to this board no problems using the one available here.
https://micropython.org/download/esp32c3/
Just make sure to change `-z 0x1000` to `-z 0x0`
Micropython works great so far on this board!

wolfen351, 2021-11-19:
Thanks! Worked perfectly! :)

Closed 2021-11-19.

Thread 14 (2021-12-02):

Access Grove Connector

vince925, 2021-12-02:
I am trying to read data from Grove connector (Multichannel Gas Sensor v2.0).  There is an LED that lights up when connected to a Seeed Device (and I can read data).  On my LILYGO mini D1 Plus v1.2 (ESP32C3), it is not lighting up nor do I see any data on SDA/SCL.  I measured voltage - v3.28 which is fine.  I am trying to read SCL (18) and SDA (19). Has anyone gotten the Grove connector to work?  Could I get an example?
Thanks in Advance, Vince

MadGeometer, 2022-02-20:
I'm also having problems with the Grove connector on T-OI Plus. I'm using a known working device with I2C address 0x3E. Also using SDA=19 and SCL=18.

I'm powering T-IO Plus using USB, but the I2C device doesn't seem to be getting any power.

Any ideas?

vince925, 2022-02-20:
Mike,

     It sounds like you are running into the same issue as me.  I have a grove connector device that has a little led power indicator.  It lights up when connected to a WIO Terminal, but not when connected to the T-IO Plus.  I checked the power from the T-IO Plus and read 3.28v.  I did not check the AMPS which in hind sight I should have.  I connected another device to the main board on the T-IO (not the grove connector) and it worked.  I will check the AMPS on the grove connector on Tuesday and let you know.  I want to use the T-IO Plus as it has perfect form for several of my projects.  I was hoping a new firmware release would help, but have not seen any.  I tried contacting the folks at Lilygo and did get a response but it did not help.  If you could try contacting them that may help.  Let me know if you have any suggestions.

Vince

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

MadGeometer, 2022-02-20:
Hi Vince,

I'd interested in what you find out! I got a good deal on the T-OIs and am looking forward to using them!

Thanks,
Mike

LilyGO, 2022-02-22:
I use Grove to use everything fine.  Can you scan the I2C address now?  No electricity?  Is the sensor connected to 3.3V?

vince925, 2022-02-23:
I have tried scanning for I2C devices - if I scan without a device attached, it returns no devices found.  If I attach a device, it will hang or crash the T-IO Plus.  I have tried a couple mini D1 plus.  I have also tried several I2C devices.  I also uploaded the firmware "LilyGo-T-OI-plus_2021-7-17" with no success.  I am using seeedstudio devices (Multichannel Gas Sensor v2.0, HCHO Sensor v1.0, Temperature & Humitity Sensor Pro v1.3.  Have you used any seeedstudio grove devices?  I want T-IO's to work because they are perfect form and concept for my projects.  Please help, Vince

LilyGO, 2022-02-23:
#include "Wire.h"
#include "Arduino.h"

#define SDA 18
#define SCL 19

void setup()
{
    Serial.begin (115200); // Leonardo: wait for serial port to connect
    while (!Serial) { }
    Serial.println ();
    Serial.println ("I2C scanner. Scanning ...");
    unsigned char count = 0;
    Wire.begin(SDA, SCL);
    for (unsigned char i = 8; i < 120; i++) {
        Wire.beginTransmission (i);
        if (Wire.endTransmission () == 0) {
            Serial.print ("Found address: ");
            Serial.print (i, DEC);
            Serial.print (" (0x");
            Serial.print (i, HEX);
            Serial.println (")");
            count++;
            delay (1); // maybe unneeded?
        } // end of good response
    } // end of for loop
    Serial.println ("Done.");
    Serial.print ("Found ");
    Serial.print (count, DEC);
    Serial.println (" device(s).");
} // end of setup
void loop() {}

LilyGO, 2022-02-23:
What does the serial port print using the above code?

vince925, 2022-02-26:
I received the following output (COM14 / USB-C):

09:36:18.793 -> ESP-ROM:esp32c3-api1-20210207

09:36:18.793 -> Build:Feb  7 2021

09:36:18.793 -> rst:0x1 (POWERON),boot:0xd (SPI_FAST_FLASH_BOOT)

09:36:18.793 -> SPIWP:0xee

09:36:18.793 -> mode:DIO, clock div:1

09:36:18.793 -> load:0x3fcd6100,len:0x420

09:36:18.793 -> load:0x403ce000,len:0x90c

09:36:18.793 -> load:0x403d0000,len:0x236c

09:36:18.793 -> SHA-256 comparison failed:

09:36:18.793 -> Calculated: ccb0d00bac7e84e1d90a12e4f75f4ab6c5f7e71bb209afd5819c4c9557a6db71

09:36:18.839 -> Expected: c9cf160580940ec7801c73b16423824e72ad12055c732e83ce66332240af42a7

09:36:18.839 -> Attempting to boot anyway...

09:36:18.839 -> entry 0x403ce000

09:36:18.886 ->

09:36:18.886 -> I2C scanner. Scanning ...

09:36:24.881 -> E (11092) task_wdt: Task watchdog got triggered. The following tasks did not reset the watchdog in time:

09:36:24.881 -> E (11092) task_wdt:  - IDLE (CPU 0)

09:36:24.881 -> E (11092) task_wdt: Tasks currently running:

09:36:24.881 -> E (11092) task_wdt: CPU 0: loopTask

09:36:29.894 -> E (16092) task_wdt: Task watchdog got triggered. The following tasks did not reset the watchdog in time:

09:36:29.894 -> E (16092) task_wdt:  - IDLE (CPU 0)

09:36:29.894 -> E (16092) task_wdt: Tasks currently running:

09:36:29.894 -> E (16092) task_wdt: CPU 0: loopTask

09:36:34.892 -> E (21092) task_wdt: Task watchdog got triggered. The following tasks did not reset the watchdog in time:

09:36:34.892 -> E (21092) task_wdt:  - IDLE (CPU 0)

09:36:34.892 -> E (21092) task_wdt: Tasks currently running:

09:36:34.892 -> E (21092) task_wdt: CPU 0: loopTask

09:36:39.850 -> E (26092) task_wdt: Task watchdog got triggered. The following tasks did not reset the watchdog in time:

09:36:39.898 -> E (26092) task_wdt:  - IDLE (CPU 0)

It shows firmware 2/7/2021 Temperature & Humidity Sensor Pro v1.3 was attached to the T-IO Plus.  I was using Arduino v1.8.19.  I cut/paste your code into the gui.

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

MadGeometer, 2022-02-26:
Hi Vince and LilyGO

OK, got it figured out...
The pins on the T-OI board's Grove connector are backwards from the usual Grove connector!

Order on T-OI is GRD, 3V3, SCL, SDA
Order on usual Grove sensor is SCL, SDA, VCC, GND

Attached photo for proof.

Thanks,
Mike K

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

vince925, 2022-02-26:
Mike,

     It is totally assume that you were able to figure out the wiring / connection issue.  LilyGo will have to correct this probably with a hardware change.  In the meantime, how would you suggest to correct for the issue – make a short cross over cable or just re-pin the cable?

Great detective work, Vince

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

vince925, 2022-02-26:
Mike,

     From your picture, more is swapped.  It is almost a mirror image?

From T-IO Plus side:

    Black    -> White,

    Red      -> Yellow

    White  -> Red

    Yellow -> Black

Vince

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

MadGeometer, 2022-02-26:
Yes, it is NOT a reversal

mailinger-mate, 2022-10-25:
@LilyGO any chance a newer version of the board will receive a fix for the Grove wiring?

LilyGO, 2022-11-14:
Do you mean we have a mistake in this image recognition? We've finished changing it
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

vince925, 2022-11-14:
LilyGO,
     I saw that there is a new version of LilyGo-T-OI-PLUS  (2022-06-20).  What is different.  Even changing the pinout on a V1.2 board (20210922 with firmware update), I have not been able to get a Grove device to work (I have 2: Multichannel Gas Sensor v2.0 and Temperature & Humidity Sensor Pro v1.3).  The sensors work on a WIO Terminal.  Neither work using Seeed Library / demo

LilyGO, 2022-11-14:
Just change the serial chip. You make sure your code SDA and SCL correspond to your wiring.

mailinger-mate, 2022-11-19:
@LilyGO according to the [latest pinout on master](https://github.com/Xinyuan-LilyGO/LilyGo-T-OI-PLUS/blob/main/image/new_TOI_Plus.png) the Grove mount wiring is still *incorrect*.

The [Grove interface specifications](https://wiki.seeedstudio.com/Grove_System/#interface-of-grove-modules) defines the correct wiring as:
- pin 1 - Yellow (for example, SCL on I2C Grove Connectors)
- pin 2 - White (for example, SDA on I2C Grove Connectors)
- pin 3 - Red - VCC on all Grove Connectors
- pin 4 - Black - GND on all Grove Connectors

However as @vince925 also pointed out on the T-OI board the wiring is **incorrectly the mirrored opposite**, and since the connector is polarized, and the currently the yellow SCL/SDA signal wire can only ever be inserted to GND on the T-OI.

For example, on the [SW-420 Grove vibration sensor pin map](https://wiki.seeedstudio.com/Grove-Vibration_Sensor_SW-420/#pin-map) you can see can see how the Pin 1 wire is supposed to be SIG for vibration signal:

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

And to illustrate the vibration sensor connected to a T-OI with the pin map displayed, maybe the problem seems more obvious:

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

Is this something I can also fix in code?

vince925, 2022-11-24:
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

I am using the multi gas sensor from Seeed Studio.  It is finally working.  The T OI Plus would short out if I had the power backwards.  WireScan would not find the sensor until I wired the cable as seen in the picture (it seemed to work when I used individual wires - but red and black were reversed which makes not sense).  Now that it works - this will be the best solution (better than the Wemos C3 mini) - it just should not be this hard.

vince925, 2022-11-24:
No - since power and SDA/SCL are reversed it can not be corrected in software alone

vince925, 2022-11-24:
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

I am using the multi gas sensor from Seeed Studio. It is finally working. The T OI Plus would short out if I had the power backwards. WireScan would not find the sensor until I wired the cable as seen in the picture (it seemed to work when I used individual wires - but red and black were reversed which makes no sense). Now that it works - this will be the best solution (better than the Wemos C3 mini) - it just should not be this hard.

vince925, 2022-11-25:
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

I tried a DHT sensor from Seeed Studio.  I had to swap the yellow & white pins on the T OI Plus side (power / ground)  This does not make sense to me - but it worked.

mailinger-mate, 2022-12-03:
> 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
>
> I am using the multi gas sensor from Seeed Studio. It is finally working. The T OI Plus would short out if I had the power backwards. WireScan would not find the sensor until I wired the cable as seen in the picture (it seemed to work when I used individual wires - but red and black were reversed which makes no sense). Now that it works - this will be the best solution (better than the Wemos C3 mini) - it just should not be this hard.

@vince925 nice job, i am just wondering, where did you get the Groove connector with the reverse wiring you shared the first photo of? Did you make it yourself?

vince673, 2022-12-03:
I removed the pins on the cable side used to plug into the T OI Plus (Grove).  Then I plugged them back in the order needed.

vince673, 2022-12-03:
I forgot to mention - there is something screwy going on - You may need a different configuration, but overall this is a nice board with good connections - just needs more work by LilyGO designers

mailinger-mate, 2022-12-03:
> I removed the pins on the cable side used to plug into the T OI Plus (Grove). Then I plugged them back in the order needed.

Hehe, great idea!

JpEncausse, 2024-03-21:
Question to Grove / P-OI experts :
Is it possible to go deepsleep on battery then wakeup from grove sensor ?
[I'd love to do something like this guy](https://www.youtube.com/watch?v=he_Z-mDLnlM) with a Contact / PIR / ToF sensor to detect a door open.

mailinger-mate, 2024-06-16:
@JpEncausse have you managed to trigger wakeup from grove sensor?

Ivoz, 2025-01-19:
Yes, just found this out. The board's Grove connector connected the SDA and SCL in the wrong order. You'll have to re-wire your cable to work with this board

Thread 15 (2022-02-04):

USB-C voltage trigger

pepsi-zero, 2022-02-04:
CC1 is connected to CC2 and share only 1 resistor. According to the USB PD2 design documentation must have CC1 and CC2 each have it’s own 5k1 resistor.

LeDominik, 2022-03-12:
Yeah, this is probably the reason why this board is super-sensitive with chargers... The initial Raspberry Pi 4 had that "error" as well...

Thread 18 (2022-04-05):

Can not program the board when Li-Po battery is attached

pymo, 2022-04-05:
When Li-Po battery is attached to the board, and the board connects to PC via USB, the PC (using Arduino) can not find the COM port, thus not able to program the board. After desoldering the battery, the COM port appears and program succeeded.

This is annoying because I had to desolder the battery everytime I change the program.

LilyGO, 2022-04-06:
Hello, I have tried, there is no problem you said.  How do you connect the battery?  Can you take a picture for me?

pymo, 2022-04-20:
Sorry, it turns out to be my USB hub's problem. It does not provide enough current. I plugged it to the USB port directly on the motherboard and it works fine.

Closed 2022-04-20.

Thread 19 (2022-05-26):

Measuring Vbat

ckuehnel, 2022-05-26:
I want to measure the voltage of Vbat and use the folllowing program:

```
void setup()
{
  Serial.begin(115200);

  analogReadResolution(12);
  analogSetAttenuation(ADC_11db);
}

void loop()
{
  // read the analog / millivolts value for GPIO2:
  int analogValue = analogRead(2);
  int analogVolts = analogReadMilliVolts(2);
  float temp = temperatureRead();

  // print out the values you read:
  Serial.printf("ADC analog value = %d\n",analogValue);
  Serial.printf("ADC millivolts value = %d\n",analogVolts);
  Serial.printf("Core temperature = %3.1f °C\n\n", temp);

  delay(2000);  // delay in between reads for clear read from serial
}
```
The output is:
E (798844) tsens: Do not configure the temp sensor when it's running!
E (798844) tsens: Temperature sensor is already running or not be configured
ADC analog value = 2954
ADC millivolts value = 1407
Core temperature = 44.6 °C

I expect a voltage of about 2000 mV for a full loaded battery.What means the tsens output?

am009, 2022-05-28:
I am also trying to measure the voltage of Vbat. According to my previous experience on T-Display board, the maximum measuring range of the esp32 series chip is 0 mV ~ 2500 mV (https://docs.espressif.com/projects/esp-idf/zh_CN/latest/esp32c3/api-reference/peripherals/adc.html ). So, for a 3.7V battery, usually the adc pin only measures half of the voltage:
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
By looking at the schematic, this seems to be the case. the connection is GND -> R13(100K) -> R7(0) -> A0 -> R26 -> Vbat, and the adc is mesuring the volt between R13 and GND. So, simply double the voltage.

am009, 2022-05-28:
My current code to get volt is:

```c

// see https://github.com/espressif/esp-idf/blob/master/examples/peripherals/adc/single_read/single_read/main/single_read.c
esp_adc_cal_characteristics_t adc_chars;

void battery_adc_init()
{
  esp_err_t ret;
  bool cali_enable = false;
  esp_adc_cal_value_t val_type;
  ret = esp_adc_cal_check_efuse(ESP_ADC_CAL_VAL_EFUSE_TP);
  if (ret == ESP_ERR_NOT_SUPPORTED) {
      Serial.println("Calibration scheme not supported, skip software calibration");
  } else if (ret == ESP_ERR_INVALID_VERSION) {
      Serial.println("eFuse not burnt, skip software calibration");
  } else if (ret == ESP_OK) {
      cali_enable = true;
  } else {
      Serial.println("Invalid arg");
  }

  val_type = esp_adc_cal_characterize(ADC_UNIT_1, ADC_ATTEN_DB_11, ADC_WIDTH_BIT_12, 0, &adc_chars);
  if (val_type == ESP_ADC_CAL_VAL_EFUSE_TP)
  {
    Serial.printf("Two Point --> coeff_a:%umV coeff_b:%umV\n", adc_chars.coeff_a, adc_chars.coeff_b);// Two Point --> coeff_a:47304mV coeff_b:0mV
  }
  else
  {
    Serial.println("Unknown Calibration");
  }

  adc1_config_width(ADC_WIDTH_BIT_12);
  adc1_config_channel_atten(ADC1_CHANNEL_2, ADC_ATTEN_DB_11); // ADC1_CHANNEL_2 => GPIO2
}

uint32_t get_battery_mvolt() {
  int raw = adc1_get_raw(ADC1_CHANNEL_2); // GPIO2
  uint32_t volt = esp_adc_cal_raw_to_voltage(raw, &adc_chars); // mVolt
  return volt;
}
```

There is no `#ifdef CONFIG_IDF_TARGET_ESP32C3` in https://github.com/espressif/arduino-esp32/blob/master/cores/esp32/esp32-hal-adc.c . I guess directly using analogReadMilliVolts will return an uncalibrated result.

ckuehnel, 2022-05-28:
Thats clear. I should meassure the voltage output via serial monitor at A0. But, the values differ. Dr. Claus Kühnel - Talstr. 13b - CH-8852 AltendorfMobile +41-76-3960801
-------- Ursprüngliche Nachricht --------Von: am009 ***@***.***> Datum: 28.05.22  07:08  (GMT+01:00) An: Xinyuan-LilyGO/LilyGo-T-OI-PLUS ***@***.***> Cc: Claus Kühnel ***@***.***>, Author ***@***.***> Betreff: Re: [Xinyuan-LilyGO/LilyGo-T-OI-PLUS] Measuring Vbat (Issue #19)
I am also trying to measure the voltage of Vbat. According to my previous experience on T-Display board, the maximum measuring range of the esp32 series chip is 0 mV ~ 2500 mV (https://docs.espressif.com/projects/esp-idf/zh_CN/latest/esp32c3/api-reference/peripherals/adc.html ). So, for a 3.7V battery, usually the adc pin only measures half of the voltage:

By looking at the schematic, this seems to be the case. the connection is GND -> R13(100K) -> R7(0) -> A0 -> R26 -> Vbat, and the adc is mesuring the volt between R13 and GND. So, simply double the voltage.

—Reply to this email directly, view it on GitHub, or unsubscribe.You are receiving this because you authored the thread.Message ID: ***@***.***>

ckuehnel, 2022-05-28:
/*
 * File: ESP32-C3_AnalogRead.ino
 * 
 * Using ADC of T-OI plus ESP32-C3
 * used Board: STAMP-C3U
 * 
 * 2022-05-27/Claus Kühnel ***@***.***
 */
 
float conversionFactor = 3300./4096;

void setup() 
{
  Serial.begin(115200);
  delay(2000); // wait for serial monitor
  Serial.println("T-OI plus ESP32-C3 ADC");
  
  analogReadResolution(12);
  analogSetAttenuation(ADC_11db); 
}

void loop() 
{
  // read the analog value for GPIO2:
  int analogValue = analogRead(2); // Reads Vbat
  // int analogVolts = analogReadMilliVolts(2); do not use this 
  int analogVolts = (int) (analogValue * conversionFactor) + .5;
  float temp = temperatureRead();
  
  // print out the values you read:
  Serial.printf("ADC analog value = %d\n",analogValue);
  Serial.printf("ADC millivolts value = %d\n",analogVolts);
  Serial.printf("Core temperature = %3.1f °C\n\n", temp);
  
  delay(2000);  // delay in between reads for clear read from serial
}

I get the following output for 2.06 V on A0:

Dr. Claus Kühnel - Talstr. 13b - CH-8852 Altendorf
Mobile +41-76-3960801
-- Aus dem Rheinwerk-Verlag: Arduino - das umfassende Handbuch ISBN 978-3-8362-7345-9 [https://www.rheinwerk-verlag.de/arduino-das-umfassende-handbuch/] -- 

Am 28.05.2022 07:08:00 schrieb am009 ***@***.***>:
I am also trying to measure the voltage of Vbat. According to my previous experience on T-Display board, the maximum measuring range of the esp32 series chip is 0 mV ~ 2500 mV (https://docs.espressif.com/projects/esp-idf/zh_CN/latest/esp32c3/api-reference/peripherals/adc.html [https://docs.espressif.com/projects/esp-idf/zh_CN/latest/esp32c3/api-reference/peripherals/adc.html] ). So, for a 3.7V battery, usually the adc pin only measures half of the voltage:
[image] [https://user-images.githubusercontent.com/23314210/170810678-96a8d7c7-91a8-47b8-952e-5ebf32fca1eb.png]
By looking at the schematic, this seems to be the case. the connection is GND -> R13(100K) -> R7(0) -> A0 -> R26 -> Vbat, and the adc is mesuring the volt between R13 and GND. So, simply double the voltage.
—
Reply to this email directly, view it on GitHub [https://github.com/Xinyuan-LilyGO/LilyGo-T-OI-PLUS/issues/19#issuecomment-1140175497], or unsubscribe [https://github.com/notifications/unsubscribe-auth/AABPZTEKZFP2ESTLDZZXU5DVMGS2VANCNFSM5XA25NRQ].
You are receiving this because you authored the thread.Message ID: ***@***.***>
[cf2c34dd-2ffc-4736-b131-183d6f40f7ac]

LilyGO, 2022-05-30:
Hello,
1. [Obtain battery voltage](https://github.com/Xinyuan-LilyGO/LilyGo-T-OI-PLUS/tree/main/example/battery_voltage).
2.The output is:
E (798844) tsens: Do not configure the temp sensor when it's running!
E (798844) tsens: Temperature sensor is already running or not be configured

This may have something to do with the ESP32 version. Or a software bug
 Submit feedback questions [here](https://github.com/espressif/arduino-esp32/issues)

ckuehnel, 2022-05-30:
Thanks a lot, it works now.

Dr. Claus Kühnel - Talstr. 13b - CH-8852 Altendorf
Mobile +41-76-3960801
-- Aus dem Rheinwerk-Verlag: Arduino - das umfassende Handbuch ISBN 978-3-8362-7345-9 [https://www.rheinwerk-verlag.de/arduino-das-umfassende-handbuch/] -- 

Am 30.05.2022 12:14:50 schrieb LilyGO ***@***.***>:
Hello,
* Obtain battery voltage [https://github.com/Xinyuan-LilyGO/LilyGo-T-OI-PLUS/tree/main/example/battery_voltage].
2.The output is:
E (798844) tsens: Do not configure the temp sensor when it's running!
E (798844) tsens: Temperature sensor is already running or not be configured
This may have something to do with the ESP32 version. Or a software bug
Submit feedback questions here [https://github.com/espressif/arduino-esp32/issues]
—
Reply to this email directly, view it on GitHub [https://github.com/Xinyuan-LilyGO/LilyGo-T-OI-PLUS/issues/19#issuecomment-1140970778], or unsubscribe [https://github.com/notifications/unsubscribe-auth/AABPZTEGPT4J756PLJSAHCLVMSIJLANCNFSM5XA25NRQ].
You are receiving this because you authored the thread.Message ID: ***@***.***>
[40b7a09a-1642-4976-9865-96118185cffb]

factoidforrest, 2023-05-10:
Soo Is vbat hardwired to one of the ADCs, or did you loop a wire from vbatt back to a pin?

Closed 2022-05-31.

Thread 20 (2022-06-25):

Deep sleep wake up by touch or sensor

mailinger-mate, 2022-06-25:
Hello!

I would like to be able to wake up the board from deep sleep using touch following this tutorial:
https://randomnerdtutorials.com/esp32-touch-wake-up-deep-sleep/

It seems the `esp_sleep_enable_touchpad_wakeup()` method is not available using PlatformIO and the Arduino framework.

Is it possible to achieve some kind of a wake up using the following method?
`  esp_deep_sleep_enable_gpio_wakeup(1ULL << 3,ESP_GPIO_WAKEUP_GPIO_HIGH);`

Could you please help me with waking up the board with touch or an external vibration sensor?
https://www.electroniclinic.com/shock-sensor-arduino-circuit-code-ky-002-shock-sensor/

Thank you!

liangyingy, 2022-06-25:
No touch sensors on ESP32-C3

liangyingy, 2022-06-25:
```c
#include <Arduino.h>
#include "esp_sleep.h"

void setup()
{
    Serial.begin(115200);
    delay(100);

    const int wakeup_time_sec = 20;
    printf("Enabling timer wakeup, %ds\n", wakeup_time_sec);
    esp_sleep_enable_timer_wakeup(wakeup_time_sec * 1000000);

    const int ext_wakeup_pin_0 = 2;
    printf("Enabling EXT0 wakeup on pin GPIO%d\n", ext_wakeup_pin_0);
    esp_deep_sleep_enable_gpio_wakeup(1 << ext_wakeup_pin_0, ESP_GPIO_WAKEUP_GPIO_LOW);
    // esp_sleep_enable_ext0_wakeup(ext_wakeup_pin_0, 1);

    esp_deep_sleep_start();
}

void loop()
{
    delay(100);
}
```

mailinger-mate, 2022-06-26:
Thank you, meanwhile i also found the Espressif documentation on the differences:
https://docs.espressif.com/projects/esp-idf/en/latest/esp32c3/hw-reference/chip-series-comparison.html

mailinger-mate, 2022-06-26:
Does  your code  example wake up the board from deep sleep when the GPIO pin #1 turns to low?
Is that pin actually exposed on the board according to the pinout?
https://github.com/Xinyuan-LilyGO/LilyGo-T-OI-PLUS/blob/main/image/new_TOI_Plus.png

liangyingy, 2022-06-27:
The code is fine, the code uses gpio2.

mailinger-mate, 2022-07-09:
Thank you, the code you suggested code is working!

Closed 2022-07-09.

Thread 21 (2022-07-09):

USB & Battery high power consumption during deep sleep

mailinger-mate, 2022-07-09:
Hello,

Based on #8 I confirmed the power consumption on *battery only* to be *40 uA* during deep sleep.

However with a fully charged *battery and USB* both connected the power consumption never goes below *35 mA*.
I am using the [deep sleep example](https://github.com/Xinyuan-LilyGO/LilyGo-T-OI-PLUS/blob/main/example/deepsleep/deepsleep.ino) provided in the repository.

How can i have external power with backup battery and charging while preserving low power consumption in deep sleep?

Thank you,
Mate

LilyGO, 2022-07-19:
Hello, Test power can only use battery test !

mailinger-mate, 2022-07-23:
@LilyGO what alternatives do I have?

ekawahyu, 2023-03-08:
@mailinger-mate I am sorry for seeing your message late. I am afraid you are gonna need a new design on the power management part. I hope that helps!

mailinger-mate, 2023-03-19:
@ekawahyu will Lilygo release a board with an improved or alternative design that fixes this?

ekawahyu, 2023-03-19:
I think that question is for LilyGo to answer. In my case, I made my own design to fit my requirement, with better low quiescent LDO and for some I completely remove it.

Closed 2022-07-19.

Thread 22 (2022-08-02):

Which pins support PWM?

esranonff, 2022-08-02:
This board looks idea for a project I'm working on, however I can't see which pins support PWM on the pin-out diagram.

I've tried various options on the board along with `analogWrite(<pin>, <valule>);` but can't even get a basic LED to fade.

Where am I going wrong?

LilyGO, 2022-08-03:
ESP32 does not support the analogWrite() function. Use the ledcWrite() function. Refer to the official example .

esranonff, 2022-08-03:
@LilyGO perfect, thanks, this is my first foray into "proper" ESP32 territory, I've been using ESP8266's up until now!

Closed 2022-08-03.

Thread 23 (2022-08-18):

How to remove the red led

jnule1a, 2022-08-18:
I would like to remove the red led to lower down power consumption during deep sleep. De-soldering it seems difficult. Which tool do I need to simply break it ?

LilyGO, 2022-08-24:
Hello, Soldering iron or heat gun

Closed 2022-08-24.

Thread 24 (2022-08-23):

Two flash memory in schematic

AlbanDurrheimer, 2022-08-23:
Hello,
Looking at the schematic of the board, I noticed that there are 2 components for the flash memory (U3 and U8).
Is this done on purpose? Or is it a mistake?
Thank you

LilyGO, 2022-08-24:
Hello，The two main components are the same.

Closed 2022-08-24.

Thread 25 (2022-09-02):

How to use external antenna? Will external antenna boost strength of sending signal?

raoulshih, 2022-09-02:
Hi All

I am trying using this device as a WiFi-tag, however the strength of the signal is a bit weak given its small antenna.
How should I do to enable use of external antenna?  For other development boards it can be done by de-soldering and re-soldering one resistor to another location, however for this board I was unable to find the information. Please advice and thanks in advance.

LilyGO, 2022-11-14:
Hello，
The same method of use. Switch the resistor to use external antenna as shown
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

Closed 2022-11-14.

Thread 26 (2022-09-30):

LILYGO TTGO T-OI Plus ESP32-C3 with 18650 battery

jnule1a, 2022-09-30:
Can LILYGO TTGO T-OI Plus ESP32-C3 charge a 3000mAh 18650 battery and how long does it take to fully charge it ?

mailinger-mate, 2022-10-25:
Yes, when the board is connected with USB-C, it will also charge the 18650 battery. I haven't measured the charging characteristics but if I remember correctly, it took maybe 10-20 minutes to charge from 80%..

Closed 2022-11-14.

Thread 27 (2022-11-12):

Deep Sleep example with ULP wakeup from I2C source

mailinger-mate, 2022-11-12:
Hello,

Could you help with a working example of deep sleep wake up using the ULP processor reads I2C signal?

Thank you,
Mate

LilyGO, 2022-11-14:
Hello，
esp32c3 has no ULP

Closed 2022-11-14.

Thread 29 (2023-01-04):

Expected battery life

wolfen351, 2023-01-04:
I am doing some measurements on my board, and thought I would share my findings about battery life:

1) Running a micropython program doing lots of calculations and about 50 temperature readings a second on a DS18B20 temperature sensor, Red LED intact, Green LED on 50% of the time, alternating on and off each cycle of the main program, with Wifi connected. No sleep code, CPU at full speed.

Battery life: 1h 20min

2) Running a micropython program doing lots of calculations and about 10 temperature readings a minute on a DS18B20 temperature sensor, Red LED intact, Green LED on 50% of the time, alternating on and off each cycle of the main program, with Wifi connected. Awake for 1 second, LIGHT sleep for 60 seconds. CPU at full speed.

Battery life: 1h 25min

I'm working on getting to 5h of battery life, with RAM intact. Next up, much longer sleep 10 min with 1 second of work each time. I'll also remove the RED led, as by all accounts that seems to eat power! Also planning on disabling the greed LED to save power.

wolfen351, 2023-01-08:
Battery life: 3h+ (still running, battery reports as 95%)

Still have the red led on. I've disabled the green LED while sleeping, and flash it at 50% when working. I only reed the DS18B20 every 5 min, and sleep for 4 min at a time. Stay awake for about 1.5s to reconnect to the network and send MQTT messaqes. The big power saving from 1h25min to now appears to be because of reading the temp sensor much less often. Still doing light sleep to preserve ram contents.

wolfen351, 2023-01-15:
Battery life: 5d

New update, I did a lot to optimise my code and reduce the work done when awake. Also made sure to reconnect to wifi/mqtt if they dropped while sleeping. I think this caused me to think the board had run out of power when in fact it had just lost wifi and never reconnected.

Terrence77, 2023-07-04:
@wolfen351 6days, that is great.  Would you mind sharing your code?

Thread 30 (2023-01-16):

Detect charging vs running on battery

wolfen351, 2023-01-16:
Is there a way to know if the board is running on AC power i.e. being charged, vs running on battery power? I'd like to do some power saving functions only if the board is without external power. I'm happy to solder a connection if that will help?

biospank, 2024-03-01:
+1. Is there any way to check if the board is in charging mode? One easy way could be checking charging led state pin if accessible by code.

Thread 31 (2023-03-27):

Run with solar power

wolfen351, 2023-03-27:
Hi all

I want to run this board using a little solar panel, and I'm wondering what panel is appropriate, and where to wire it in? Could someone with more know-how please guide me? Thanks!

I think, because the board already does voltage management to the battery for charging, I could perhaps add the panel to the usb-c input - Assuming the panel outputs >4v

NickPronto, 2023-12-04:
Without making an additional board for the raw solar panel, you run the risk of frying your board.

You could put the Lilygo T-Bat in between a raw solar panel and the T-OI, or you could find a simple solar panel with a USB output. I'd say the later is the easier option.

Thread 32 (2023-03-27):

I can't make connection with arduino ID

Jorgebar1806, 2023-03-27:
Hello, I am using version 1.8 of arduino, I have followed all the steps but I get a connection error, does anyone have a tutorial, I have installed drivers, I have put in the battery, it still recognizes the wifi ssid, the crystal, but it shows a time out error, thanks for your help, I'm using w10.

JeanBlignaut, 2024-02-06:
I have tried more than one cable and am able to use cable with other brands C3 boards. I have tried updating serial drivers too

JeanBlignaut, 2024-02-06:
I had somewhat similar experience now with Colin c3 pico but was resolved after performing steps to set that board to DFU mode - any such steps for lilygo t-io plus?

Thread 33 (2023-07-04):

Does not run on Battery

Terrence77, 2023-07-04:
I have a simple blink script.

runs fine while plugged into usb, but does not run on battery.

Is there some setting I am missing to enable the PLUS to run on battery?

Thank you.

Terrence77, 2023-07-06:
Hello, is anyone from LilyGo monitoring this Issues area?

lozaning, 2023-09-29:
The + terminal from the battery holder connects to a through hole labeled 'G' on the PCB. Did you end up swapping the polarity of the battery? Mine wont run from batteries either.

aalexff, 2024-10-31:
I'm powering it with a power supply at 4.2V connected directly on the battery terminals and it works fine.
But I haven't been able to make it work with an actual battery, it seems it's really unstable below the 4.2V mark, as 3.8V to 4.1V may or may not work.
My guess is that it has a very narrow window of working voltage,

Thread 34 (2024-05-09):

Serial Comunication Configuration 9600 baud

JpEncausse, 2024-05-09:
Hello,
I'm running example code like deepsleep or wifi. It works but the Serial is all scramble (not UTF-8 ?)

At first I didn't get any readable caracter, I swtich to `Serial.begin(9600);` it's better but still issue :

```
)�΀␄z�␔)L␌H�␎�Boot number: 1
Wakeup was not caused by deep sleep: 0
Setup ESP32 to sleep for every 10 Seconds
Going to sleep now
�'�����␜W␌.���C�c�Boot number: 2
Wakeup caused by timer
Setup ESP32 to sleep for every 10 Seconds
Going to sleep now
```

Here is my configuration

```
[platformio]
src_dir = example/deepsleep

[env:ttgo-t-oi-plus]
platform = espressif32
board = ttgo-t-oi-plus
framework = arduino

build_flags =
    -DCORE_DEBUG_LEVEL=1
```

What am I missing to get correct debug information ?

TMillesich, 2024-05-09:
Every time an ESP32 is starting up, it is sending boot messages with 115200 baud.

The boot messages printed by the ROM bootloader can be suppressed by connecting GPIO15 to GND using a resistor during boot and then still use it as an output pin after boot.

Source:
https://www.esp32.com/viewtopic.php?t=1658

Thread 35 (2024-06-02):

Non-USB serial connection trouble

SWPhantom, 2024-06-02:
I'm trying to connect a [GPS module](https://www.amazon.com/gp/product/B01D1D0F5M/ref=ppx_yo_dt_b_search_asin_title?ie=UTF8&psc=1) to the v1.3 board on pins 20 and 21.

I don't have a lot of experience using UART devices, and it makes it difficult to understand the differences between this dev board vs the raw ESP32c3 chip vs other esp32 dev boards.

1. Is it possible to communicate over Serial with a device connected to the TX and RX pins AND communicate over USB Serial with my computer (Using ArduinoIDE)?
2. If so, what's the correct way to use the serial pins with a device that communicates over UART? What's the correct way to declare a HardwareSerial object to communicate over the pins?

Here is the code:
```
#include <HardwareSerial.h>
#include <TinyGPSPlus.h>

TinyGPSPlus gps;
HardwareSerial SerialPort(2); // use UART2
void setup()
{
  Serial.begin(115200);
  SerialPort.begin(9600, SERIAL_8N1, 20, 21);
  delay(3000);
  Serial.println("beginning!");
}

void updateSerial(){
  delay(500);
  while (Serial.available())  {
    SerialPort.write(Serial.read()); // Forward what Serial received to Software Serial Port
  }
  while (SerialPort.available())  {
    Serial.write(SerialPort.read()); // Forward what Software Serial received to Serial Port
  }
}

void displayInfo()
{
  Serial.print(F("Location: "));
  if (gps.location.isValid()){
    Serial.print(gps.location.lat(), 6);
    Serial.print(F(","));
    Serial.print(gps.location.lng(), 6);
  }
  else
  {
    Serial.print(F("INVALID"));
  }
}

void loop() {
  while (SerialPort.available() > 0) {
    Serial.println("SerialPort is available");
    if (gps.encode(SerialPort.read())) {
      displayInfo();
    }
  }
  if (millis() > 10000 && gps.charsProcessed() < 10)
  {
    Serial.println(F("No GPS detected: check wiring."));
    Serial.println(gps.charsProcessed());
    while (true);
  }
}
```

My output is
```
20:38:37.481 -> beginning!
20:38:47.491 -> No GPS detected: check wiring.
20:38:47.491 -> 0
```

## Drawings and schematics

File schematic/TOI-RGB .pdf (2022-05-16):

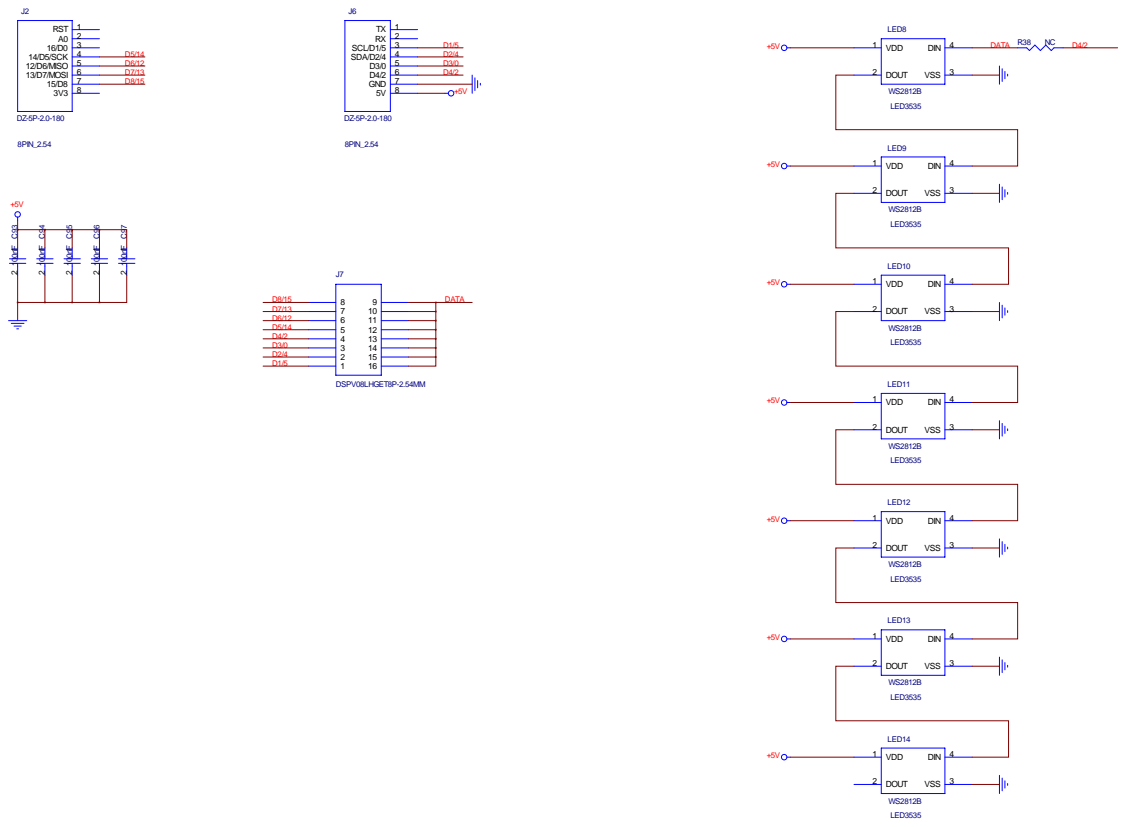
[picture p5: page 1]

Size C | Document Number | Rev ?

Date: Friday, December 27, 2019 | Sheet 1 of 1

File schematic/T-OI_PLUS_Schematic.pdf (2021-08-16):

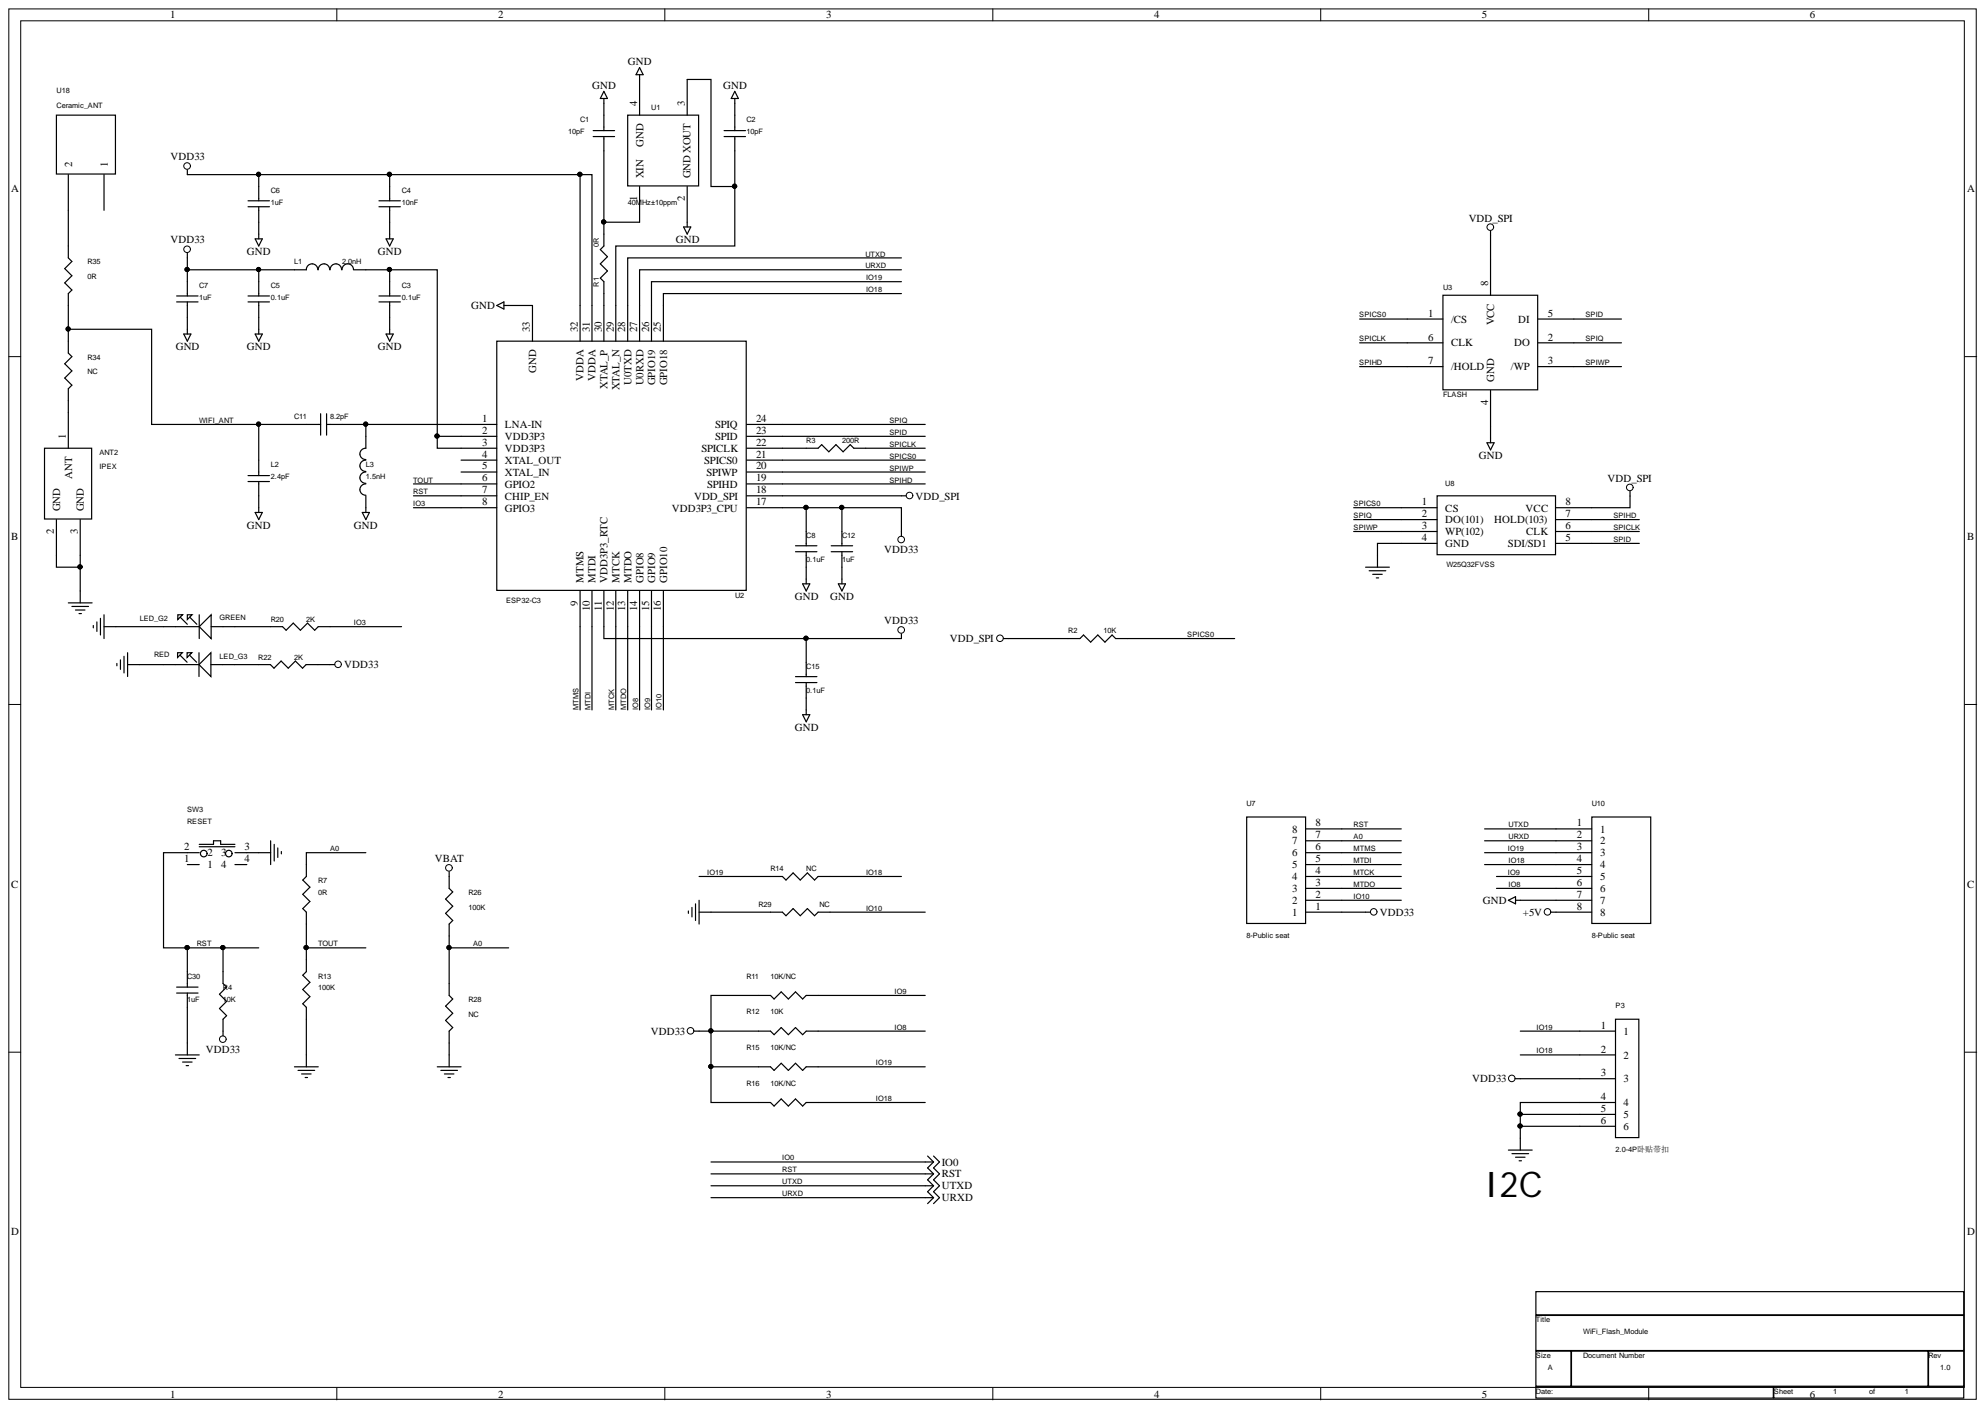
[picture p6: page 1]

U R X D
IO1 9
IO1 8

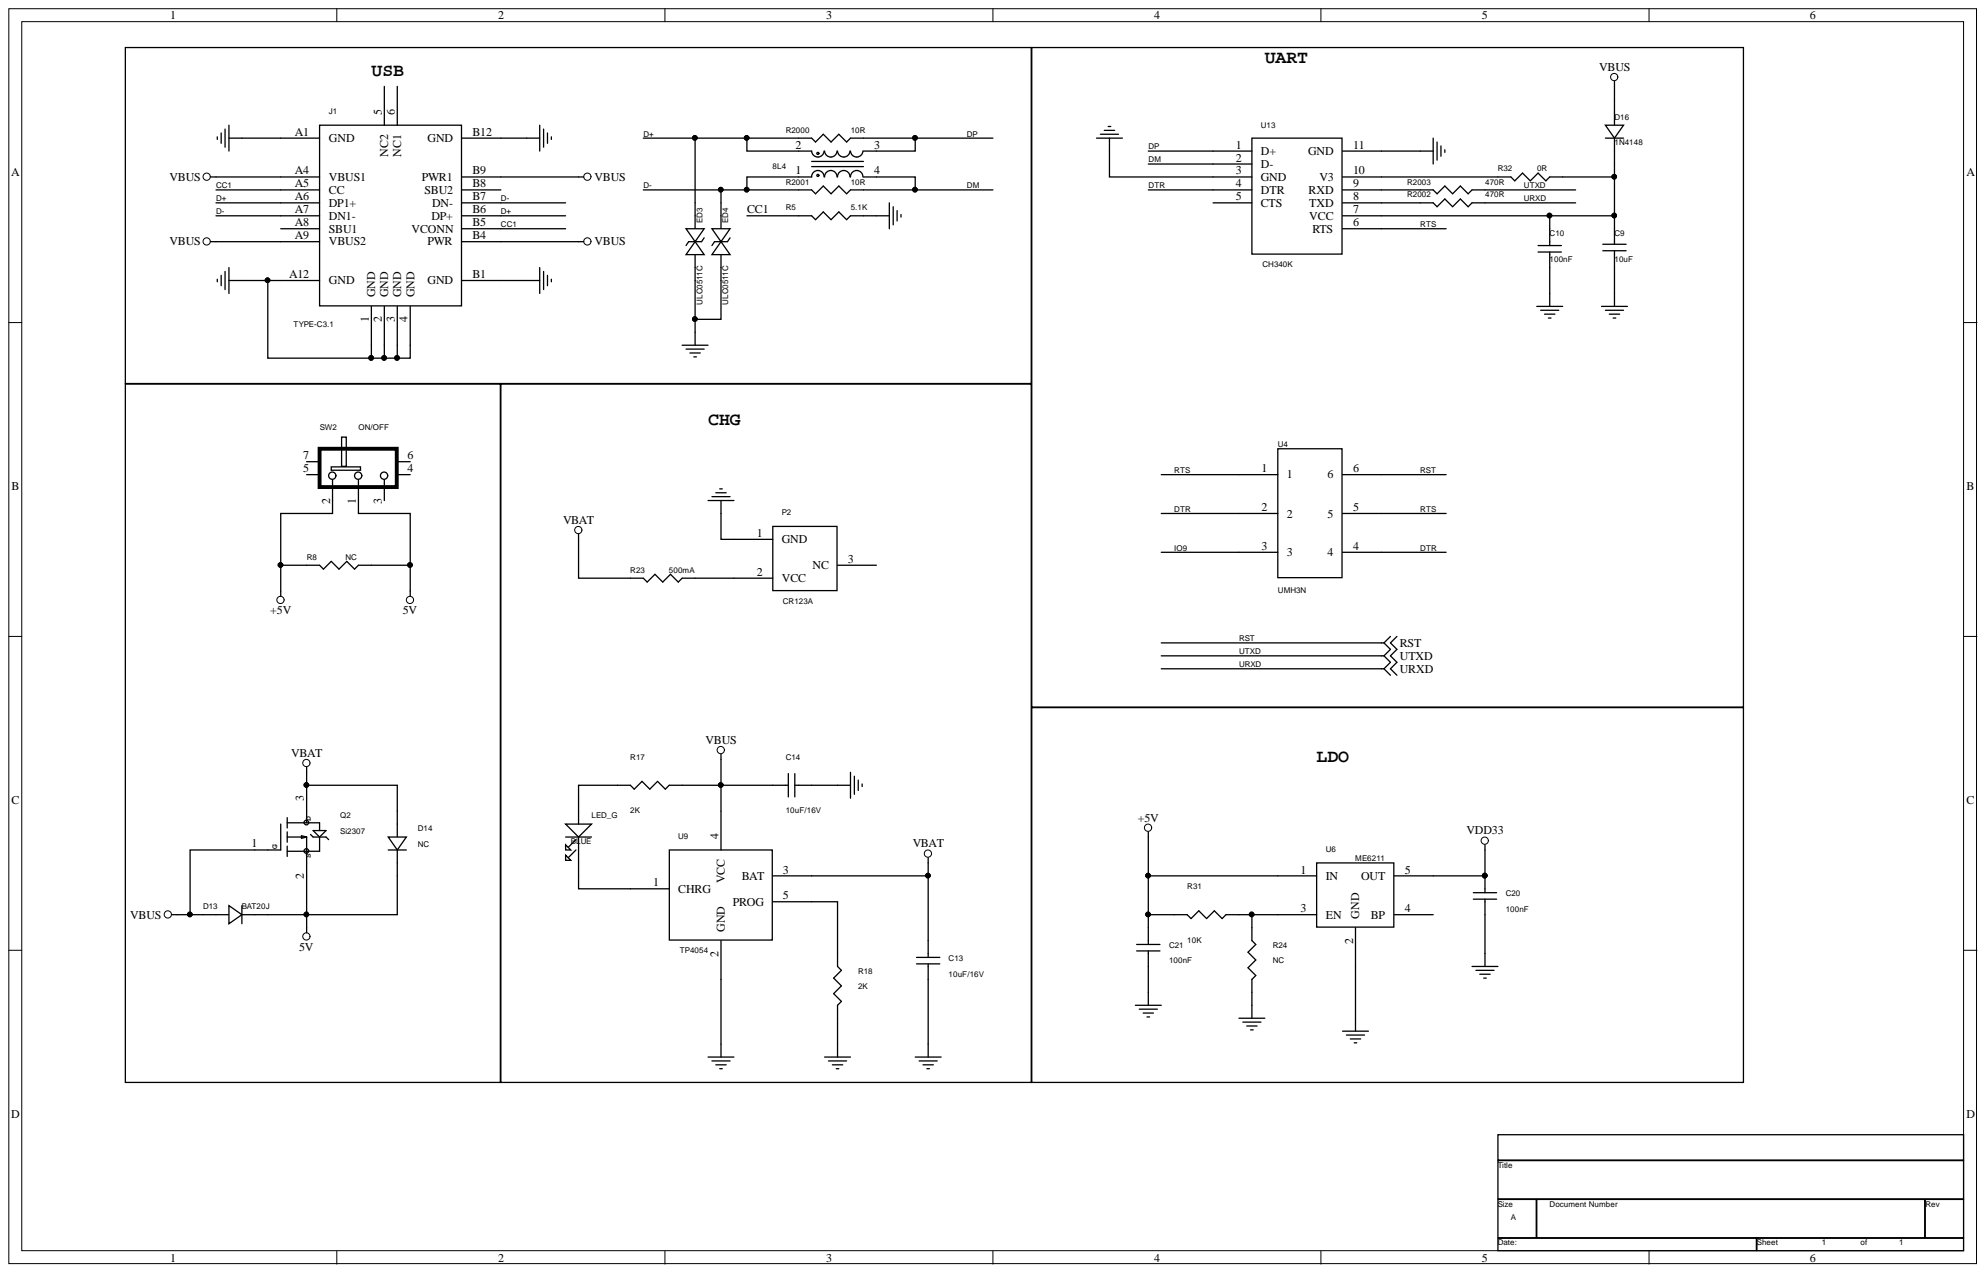
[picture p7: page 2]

Size A | Document Number | Rev

Date: | Sheet 1 of 1

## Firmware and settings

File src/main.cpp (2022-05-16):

/*
 *  This sketch demonstrates how to scan WiFi networks.
 *  The API is almost the same as with the WiFi Shield library,
 *  the most obvious difference being the different file you need to include:
 */
#include "WiFi.h"

void setup()
{
    Serial.begin(115200);

    // Set WiFi to station mode and disconnect from an AP if it was previously connected
    WiFi.mode(WIFI_STA);
    WiFi.disconnect();
    delay(100);

    Serial.println("Setup done");
}

void loop()
{
    Serial.println("scan start");

    // WiFi.scanNetworks will return the number of networks found
    int n = WiFi.scanNetworks();
    Serial.println("scan done");
    if (n == 0) {
        Serial.println("no networks found");
    } else {
        Serial.print(n);
        Serial.println(" networks found");
        for (int i = 0; i < n; ++i) {
            // Print SSID and RSSI for each network found
            Serial.print(i + 1);
            Serial.print(": ");
            Serial.print(WiFi.SSID(i));
            Serial.print(" (");
            Serial.print(WiFi.RSSI(i));
            Serial.print(")");
            Serial.println((WiFi.encryptionType(i) == WIFI_AUTH_OPEN) ? " " : "*");
            delay(10);
        }
    }
    Serial.println("");

    // Wait a bit before scanning again
    delay(5000);
}

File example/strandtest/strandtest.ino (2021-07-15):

// A basic everyday NeoPixel strip test program.

// NEOPIXEL BEST PRACTICES for most reliable operation:
// - Add 1000 uF CAPACITOR between NeoPixel strip's + and - connections.
// - MINIMIZE WIRING LENGTH between microcontroller board and first pixel.
// - NeoPixel strip's DATA-IN should pass through a 300-500 OHM RESISTOR.
// - AVOID connecting NeoPixels on a LIVE CIRCUIT. If you must, ALWAYS
//   connect GROUND (-) first, then +, then data.
// - When using a 3.3V microcontroller with a 5V-powered NeoPixel strip,
//   a LOGIC-LEVEL CONVERTER on the data line is STRONGLY RECOMMENDED.
// (Skipping these may work OK on your workbench but can fail in the field)

#include <Adafruit_NeoPixel.h>
#ifdef __AVR__
 #include <avr/power.h> // Required for 16 MHz Adafruit Trinket
#endif
//set pin
#define D1   19
#define D2   18
#define D3   9
#define D4   8
#define D5   5
#define D6   6
#define D7   7
#define D8   10


//D1 indicates that the dial switch 1 dials down to enable RGB .D2表示2。 D2 is 2.And so on....
#define LED_PIN   D1

// How many NeoPixels are attached to the Arduino?
#define LED_COUNT 7

// Declare our NeoPixel strip object:
Adafruit_NeoPixel strip(LED_COUNT, LED_PIN, NEO_GRB + NEO_KHZ800);
// Argument 1 = Number of pixels in NeoPixel strip
// Argument 2 = Arduino pin number (most are valid)
// Argument 3 = Pixel type flags, add together as needed:
//   NEO_KHZ800  800 KHz bitstream (most NeoPixel products w/WS2812 LEDs)
//   NEO_KHZ400  400 KHz (classic 'v1' (not v2) FLORA pixels, WS2811 drivers)
//   NEO_GRB     Pixels are wired for GRB bitstream (most NeoPixel products)
//   NEO_RGB     Pixels are wired for RGB bitstream (v1 FLORA pixels, not v2)
//   NEO_RGBW    Pixels are wired for RGBW bitstream (NeoPixel RGBW products)


// setup() function -- runs once at startup --------------------------------

void setup() {
  // These lines are specifically to support the Adafruit Trinket 5V 16 MHz.
  // Any other board, you can remove this part (but no harm leaving it):
#if defined(__AVR_ATtiny85__) && (F_CPU == 16000000)
  clock_prescale_set(clock_div_1);
#endif
  // END of Trinket-specific code.

  strip.begin();           // INITIALIZE NeoPixel strip object (REQUIRED)
  strip.show();            // Turn OFF all pixels ASAP
  strip.setBrightness(50); // Set BRIGHTNESS to about 1/5 (max = 255)


}


// loop() function -- runs repeatedly as long as board is on ---------------

void loop() {
  // Fill along the length of the strip in various colors...
  colorWipe(strip.Color(255,   0,   0), 50); // Red
  colorWipe(strip.Color(  0, 255,   0), 50); // Green
  colorWipe(strip.Color(  0,   0, 255), 50); // Blue

  // Do a theater marquee effect in various colors...
  theaterChase(strip.Color(127, 127, 127), 50); // White, half brightness
  theaterChase(strip.Color(127,   0,   0), 50); // Red, half brightness
  theaterChase(strip.Color(  0,   0, 127), 50); // Blue, half brightness

  rainbow(10);             // Flowing rainbow cycle along the whole strip
  theaterChaseRainbow(50); // Rainbow-enhanced theaterChase variant
}


// Some functions of our own for creating animated effects -----------------

// Fill strip pixels one after another with a color. Strip is NOT cleared
// first; anything there will be covered pixel by pixel. Pass in color
// (as a single 'packed' 32-bit value, which you can get by calling
// strip.Color(red, green, blue) as shown in the loop() function above),
// and a delay time (in milliseconds) between pixels.
void colorWipe(uint32_t color, int wait) {
  for(int i=0; i<strip.numPixels(); i++) { // For each pixel in strip...
    strip.setPixelColor(i, color);         //  Set pixel's color (in RAM)
    strip.show();                          //  Update strip to match
    delay(wait);                           //  Pause for a moment
  }
}

// Theater-marquee-style chasing lights. Pass in a color (32-bit value,
// a la strip.Color(r,g,b) as mentioned above), and a delay time (in ms)
// between frames.
void theaterChase(uint32_t color, int wait) {
  for(int a=0; a<10; a++) {  // Repeat 10 times...
    for(int b=0; b<3; b++) { //  'b' counts from 0 to 2...
      strip.clear();         //   Set all pixels in RAM to 0 (off)
      // 'c' counts up from 'b' to end of strip in steps of 3...
      for(int c=b; c<strip.numPixels(); c += 3) {
        strip.setPixelColor(c, color); // Set pixel 'c' to value 'color'
      }
      strip.show(); // Update strip with new contents
      delay(wait);  // Pause for a moment
    }
  }
}

// Rainbow cycle along whole strip. Pass delay time (in ms) between frames.
void rainbow(int wait) {
  // Hue of first pixel runs 5 complete loops through the color wheel.
  // Color wheel has a range of 65536 but it's OK if we roll over, so
  // just count from 0 to 5*65536. Adding 256 to firstPixelHue each time
  // means we'll make 5*65536/256 = 1280 passes through this outer loop:
  for(long firstPixelHue = 0; firstPixelHue < 5*65536; firstPixelHue += 256) {
    for(int i=0; i<strip.numPixels(); i++) { // For each pixel in strip...
      // Offset pixel hue by an amount to make one full revolution of the
      // color wheel (range of 65536) along the length of the strip
      // (strip.numPixels() steps):
      int pixelHue = firstPixelHue + (i * 65536L / strip.numPixels());
      // strip.ColorHSV() can take 1 or 3 arguments: a hue (0 to 65535) or
      // optionally add saturation and value (brightness) (each 0 to 255).
      // Here we're using just the single-argument hue variant. The result
      // is passed through strip.gamma32() to provide 'truer' colors
      // before assigning to each pixel:
      strip.setPixelColor(i, strip.gamma32(strip.ColorHSV(pixelHue)));
    }
    strip.show(); // Update strip with new contents
    delay(wait);  // Pause for a moment
  }
}

// Rainbow-enhanced theater marquee. Pass delay time (in ms) between frames.
void theaterChaseRainbow(int wait) {
  int firstPixelHue = 0;     // First pixel starts at red (hue 0)
  for(int a=0; a<30; a++) {  // Repeat 30 times...
    for(int b=0; b<3; b++) { //  'b' counts from 0 to 2...
      strip.clear();         //   Set all pixels in RAM to 0 (off)
      // 'c' counts up from 'b' to end of strip in increments of 3...
      for(int c=b; c<strip.numPixels(); c += 3) {
        // hue of pixel 'c' is offset by an amount to make one full
        // revolution of the color wheel (range 65536) along the length
        // of the strip (strip.numPixels() steps):
        int      hue   = firstPixelHue + c * 65536L / strip.numPixels();
        uint32_t color = strip.gamma32(strip.ColorHSV(hue)); // hue -> RGB
        strip.setPixelColor(c, color); // Set pixel 'c' to value 'color'
      }
      strip.show();                // Update strip with new contents
      delay(wait);                 // Pause for a moment
      firstPixelHue += 65536 / 90; // One cycle of color wheel over 90 frames
    }
  }
}

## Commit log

2021-08-16 Upload schematic file
2022-04-23 T-OI RGB schematic upload
2022-05-16 feature：Support platformIO
2022-05-30 test：Obtain battery voltage
2023-02-16 Dimensions upload
    [T-OI_Plus.dwg]
